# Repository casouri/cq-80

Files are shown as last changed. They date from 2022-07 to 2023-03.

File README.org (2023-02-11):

#+TITLE: CQ-80 Terminal (NAMACO端末) replica

Custom CQ-80 terminal replica! Not only is it 100% accurate, I also added Bluetooth music playback control feature. The shell is 3d printed, and the electronics are made of off-the-shelf parts.

This repository contains all the source files for the 3d model, PCB board design, etc. For a guide on making your own replica, visit: [[https://casouri.github.io/cq-80/guide-en.html][DIY Guide for CQ-80 Replica]].

For more pics, visit [[https://casouri.github.io/cq-80][CQ-80 Replica]].

#+attr_html: :width 100%
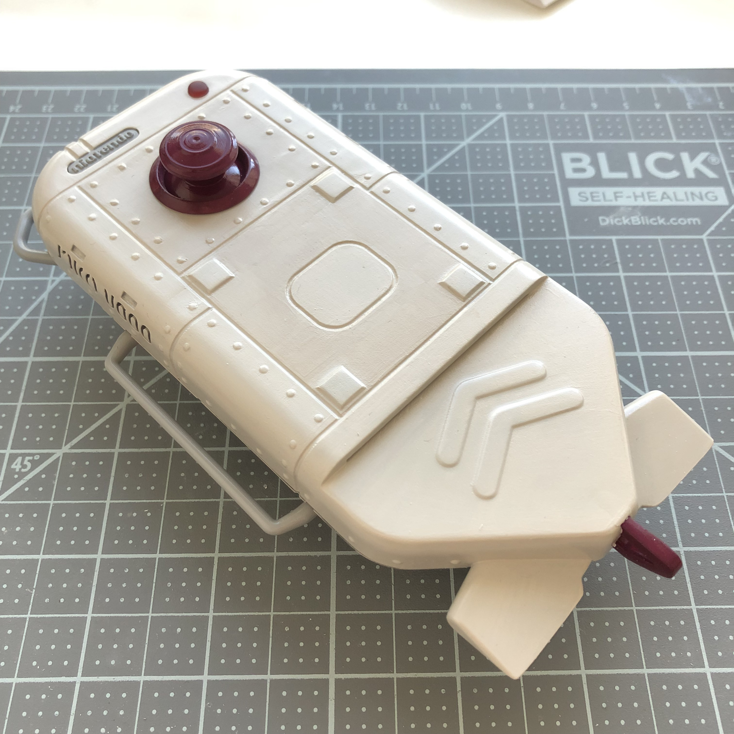
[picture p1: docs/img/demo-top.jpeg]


#+attr_html: :width 100%
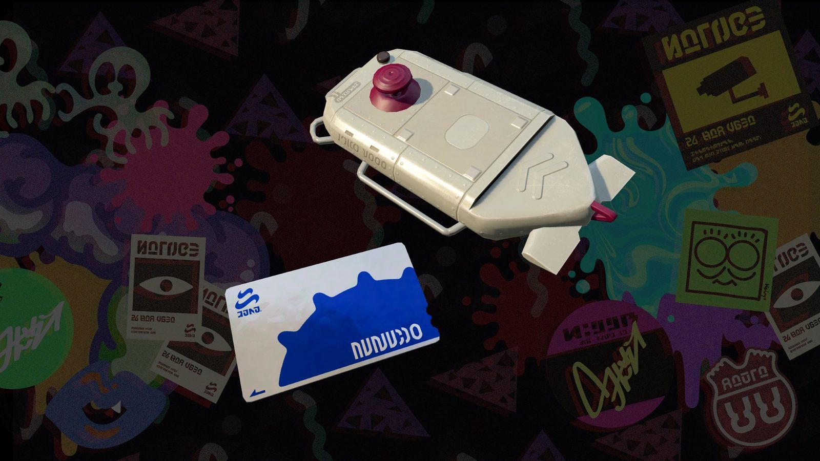
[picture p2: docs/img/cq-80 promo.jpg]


#+attr_html: :width 100%
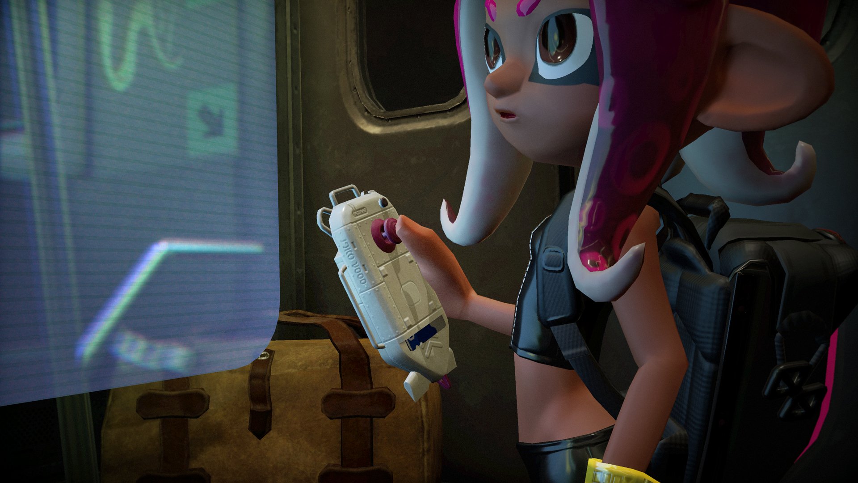
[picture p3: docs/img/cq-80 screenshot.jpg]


#+attr_html: :width 100%
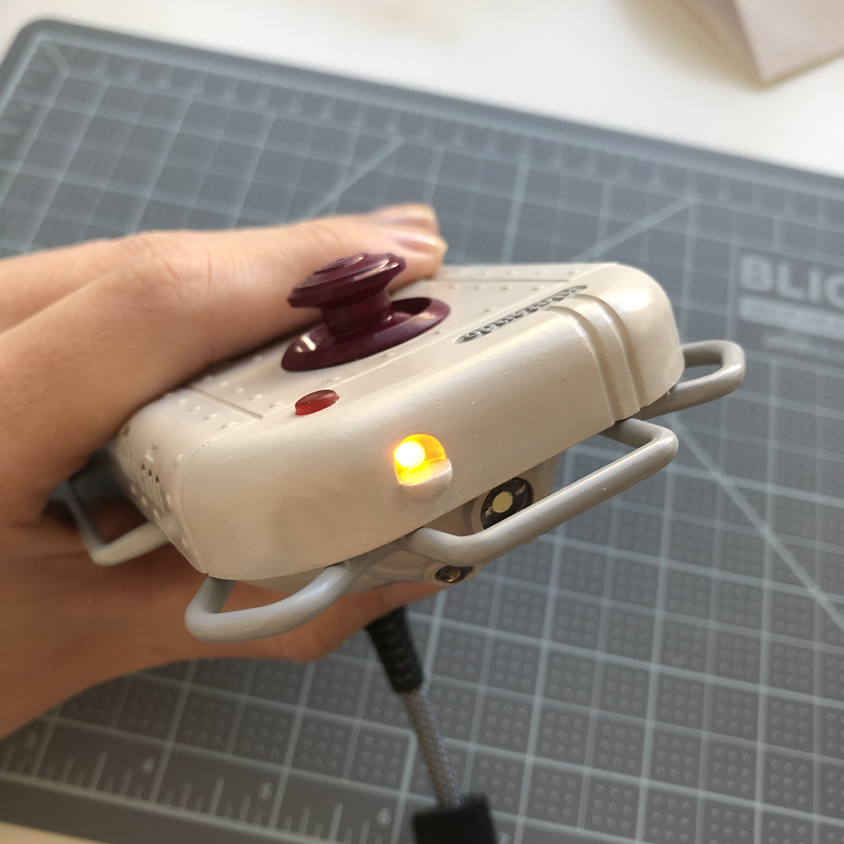
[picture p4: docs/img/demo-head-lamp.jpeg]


#+attr_html: :width 100%
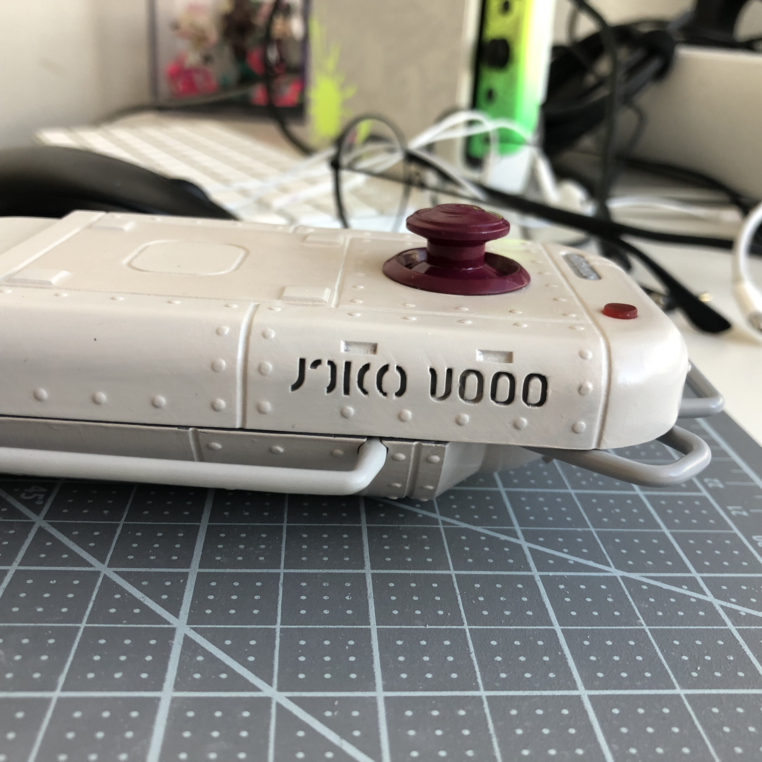
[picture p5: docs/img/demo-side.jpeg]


#+attr_html: :width 100%
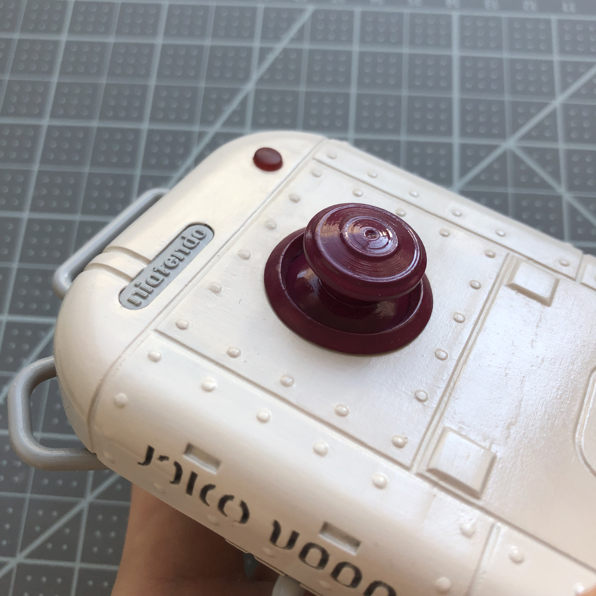
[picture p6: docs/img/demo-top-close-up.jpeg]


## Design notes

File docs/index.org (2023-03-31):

#+TITLE: CQ-80 Terminal Replica
#+HTML_HEAD: <link id="style" rel="stylesheet" type="text/css" href="./style.css"/>
#+OPTIONS: ^:nil

Custom CQ-80 terminal replica! Not only is it 100% accurate, I also added Bluetooth music playback control feature. The shell is 3d printed, and the electronics are made of off-the-shelf parts.

For a guide on making your own replica, visit: [[https://casouri.github.io/cq-80/guide-en.html][DIY Guide for CQ-80 Replica]].

#+CAPTION: Top view. The actual color is more grey than in the photo.
#+attr_html: :width 100%


#+CAPTION: The original.
#+attr_html: :width 100%


#+CAPTION: 8, my beloved...
#+attr_html: :width 100%


#+CAPTION: Font of the terminal.
#+attr_html: :width 100%
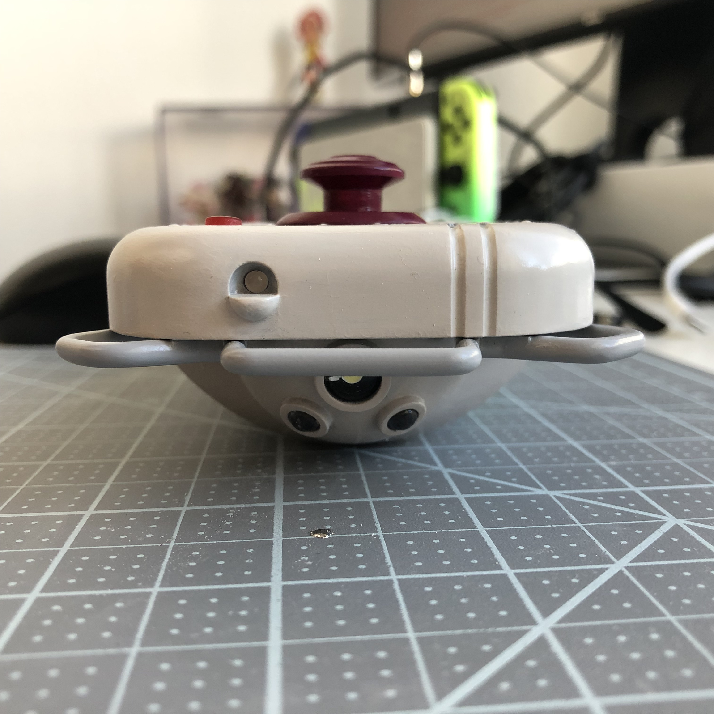
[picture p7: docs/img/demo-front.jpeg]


#+CAPTION: Compare to the in-game model.
#+attr_html: :width 100%
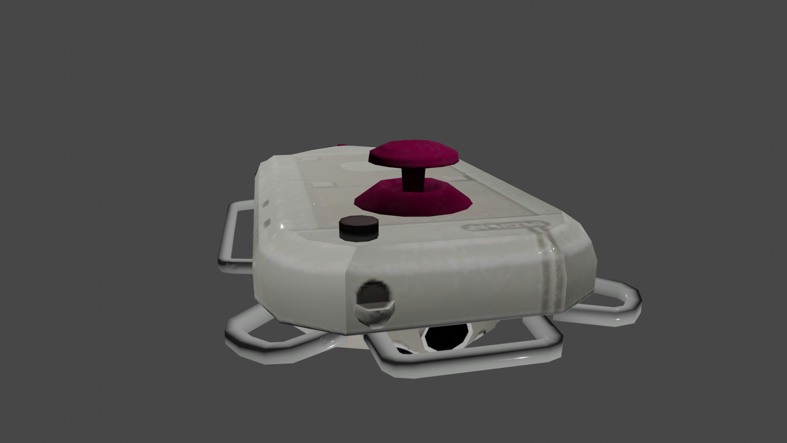
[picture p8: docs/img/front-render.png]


#+CAPTION: There are three lights in the front: one head light and two smaller side lights. The head light can be used as bathroom flashlight, and the off-white side lights can be used as night lights.
#+attr_html: :width 100%
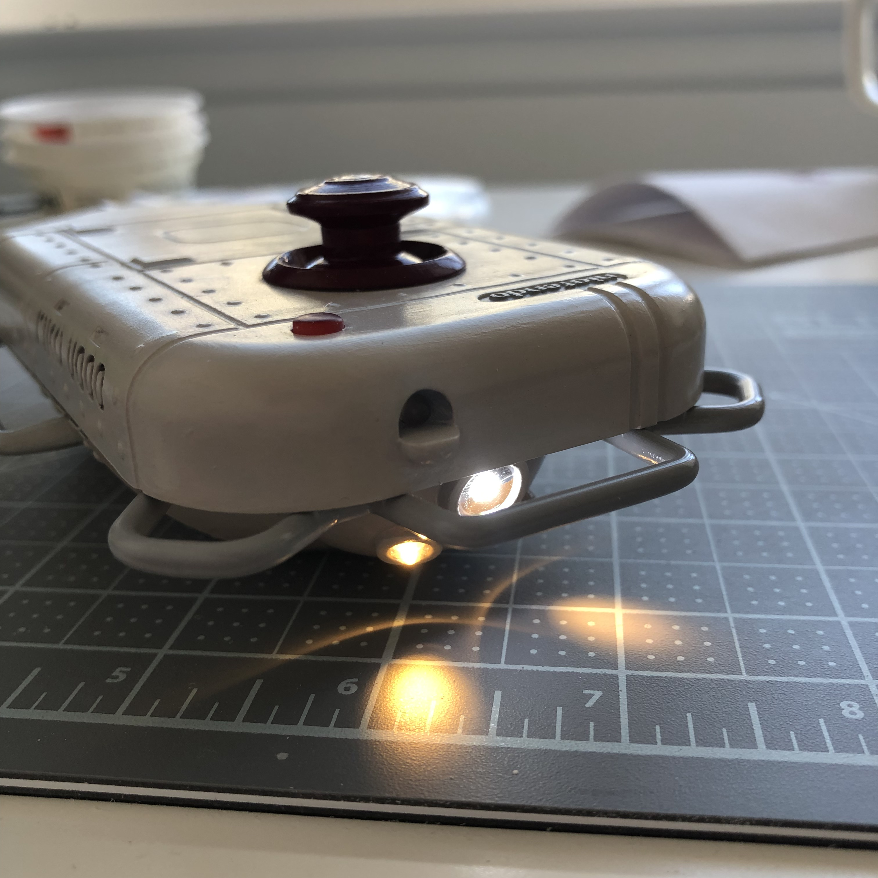
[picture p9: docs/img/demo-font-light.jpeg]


#+CAPTION: The head lamp is the charging indicator. It flashes when battery level is low, lights up when charging, and shuts off when battery is full.
#+attr_html: :width 100%


#+CAPTION: Bottom view, the USB port is the charging port.
#+attr_html: :width 100%
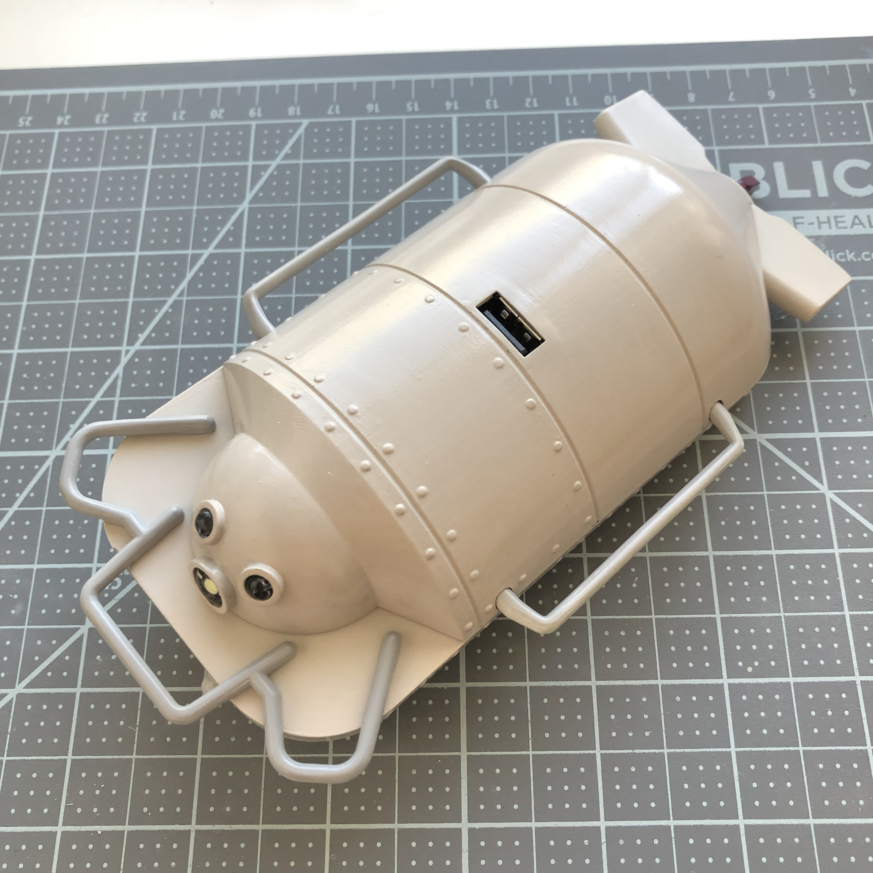
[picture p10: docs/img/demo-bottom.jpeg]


#+CAPTION: Compare to the in-game model. It has the charging port in the exact same spot.
#+attr_html: :width 100%
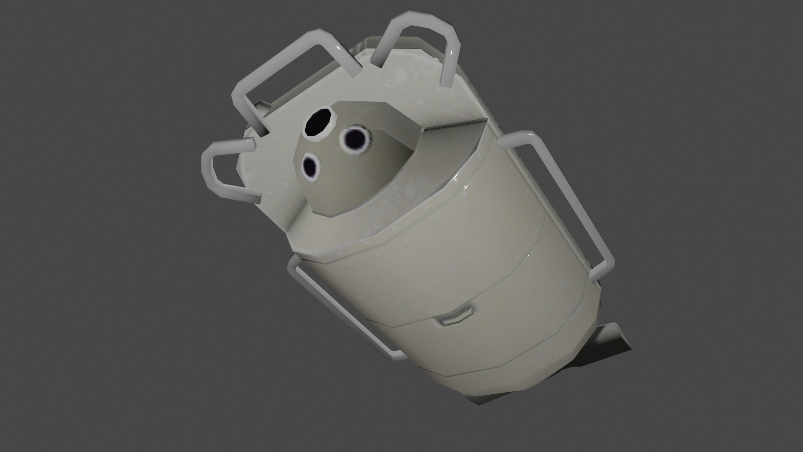
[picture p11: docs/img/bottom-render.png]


#+CAPTION: The signal light lights up when you tilt the joystick.
#+attr_html: :width 100%
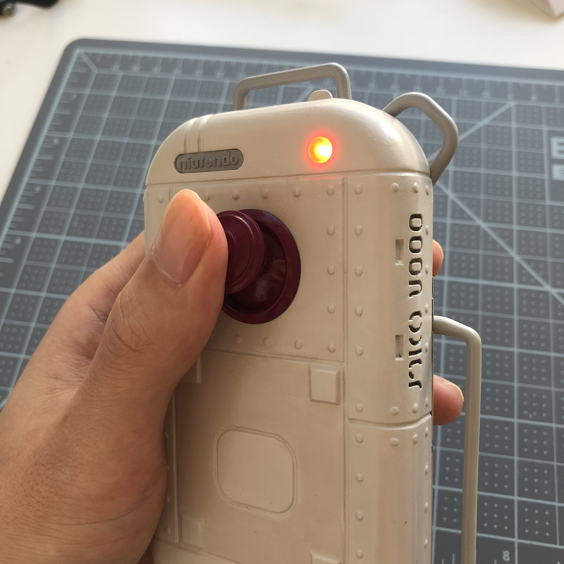
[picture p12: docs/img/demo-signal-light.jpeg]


#+CAPTION: Side emboss.
#+attr_html: :width 100%


#+CAPTION: Compare to the in-game model.
#+attr_html: :width 100%
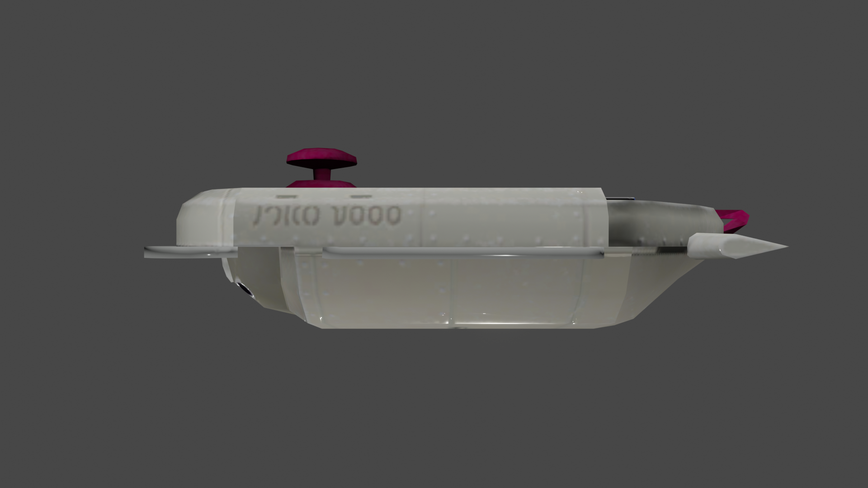
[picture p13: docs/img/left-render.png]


#+CAPTION: The tail, you can see the card slot.
#+attr_html: :width 100%
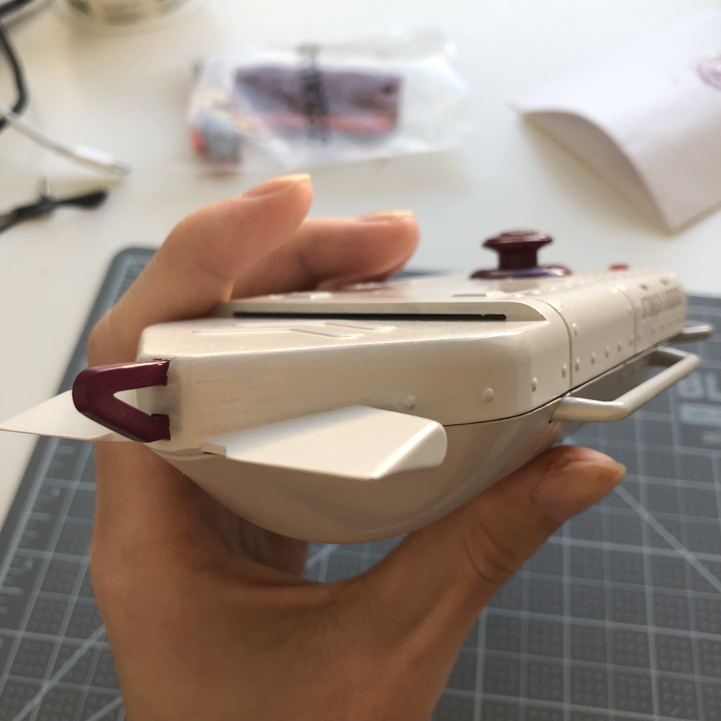
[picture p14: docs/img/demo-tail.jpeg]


#+CAPTION: A close up of the joystick.
#+attr_html: :width 100%


Here is a demo of the playback control. The controls are

| Press & hold    | Bluetooth pairing     |
| Press           | On/Off                |
| Tilt up         | Switch head lights    |
| Tilt down       | Play/Pause            |
| Tile left/right | Skip forward/backward |
| Rotate          | Volume up/down        |

#+begin_export html
<video controls width="50%">
<source src="./img/demo-playback.mp4" type="video/mp4">
</video>
#+end_export

# Local Variables:
# org-html-postamble: nil
# End:

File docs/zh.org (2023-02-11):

#+TITLE: CQ-80 Terminal (NAMACO端末)
#+HTML_HEAD: <link id="style" rel="stylesheet" type="text/css" href="./style.css"/>
#+LANGUAGE: zh-CN
#+OPTIONS: ^:nil

* 展示

自制章鱼 DLC 里的 NAMACO 终端！不光还原了外形，还加入了蓝牙音乐控制器的功能，晚上还可以把探照灯用作夜灯！3D 打印外壳和打印的电路板，不是手工达人也可以自己做！

(photo)

(photo)

(promo)

| 长按摇杆      | 匹配蓝牙设备  |
| 按一下摇杆    | 开机/关机     |
| 上推摇杆      | 切换灯光      |
| 下推摇杆      | 播放/暂停     |
| 左/右推摇杆   | 上/下一首     |
| 顺时/逆时针转 | 升高/降低音量 |

我还想加入随机/循环/快进/快退功能来着，但是可能因为这些功能不常用，电脑不能识别，可恶。

#+CAPTION: 指示灯，推动摇杆就会亮，匹配蓝牙设备的时候闪烁。

#+CAPTION: 电量指示灯，电量低的时候会缓慢闪烁，充电的时候常亮，充满电熄灭。

#+CAPTION: 头灯和副灯，副灯可以用作小夜灯，头灯可以半夜上厕所的时候当手电用www

#+CAPTION: 为了还原，终端没法容下标准尺寸的卡。读卡功能感觉有点鸡肋也没有加。

#+CAPTION: 初号机当然是紫绿配色😈

#+CAPTION: 100%细节还原。

#+CAPTION: 这个小铭牌是可以拆卸的。

#+CAPTION: 隐藏的螺丝孔。

* 还原对比

* 制作指南

这个终端还是很容易做的，毕竟部件和电路板都是打印的。只需要需要给部件染色，焊一点电子元件，上传程序到微型处理器上，最后组装到一起就行了。

因为我在北美，所以我用来 3D 打印的网站（[[https://shapeways.com][Shapeways]]）和购买各种零部件的网站对国内的乌贼来说可能没什么参考价值，想做的乌贼需要自己找一找这样的网站和商店。

** 3D 打印的部件
一共有八个需要打印的部件：顶壳底壳，摇杆和摇杆环，左右栏杆，铭牌和绳挂。3D 模型文件在 =/step= 和 =/dae= 目录下。 =step= 和 =dae= 是 3D 模型的文件格式，任何 3D 打印网站都会至少支持其中一个格式。

#+caption: 3D 打印的部件和名字标注
#+attr_html: :width 100%
#+attr_latex: :width 400px
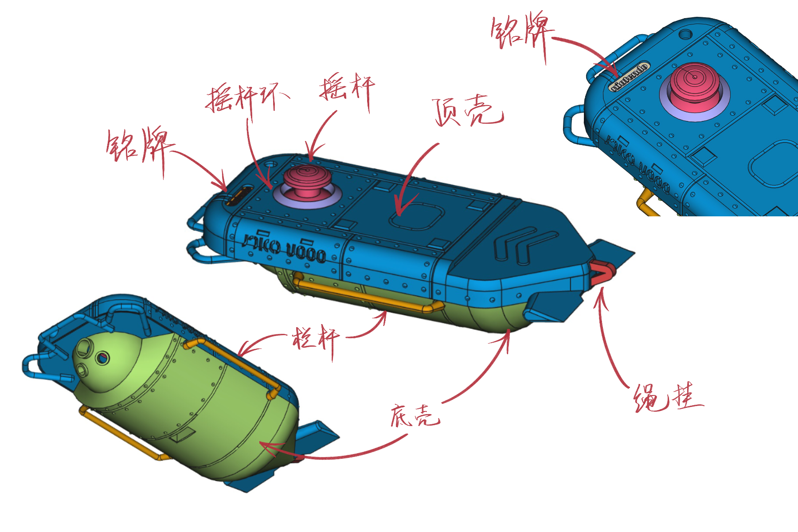
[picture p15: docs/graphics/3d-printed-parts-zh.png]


找到提供 3D 打印的网站以后，一般上传模型文件然后选择制作工艺的材料，和其他一些细节就可以了。

我推荐用 MJF 或者 SLS 的工艺和尼龙12（PA12）的材料。PA12很结实也不贵。SLA 工艺也可以，但是会更贵。

因为铭牌又小又精细，SLA 就比较适合。SLA 打印精度更高。材料的话感觉SLA支持的都可以。

别用 FDM，就是家用的 3D 打印机的工艺，精度太低，而且有些部件的结构 FDM 打印不了。

感兴趣的乌贼可以看看这篇对 3D 打印工艺的介绍：[[https://formlabs.com/blog/fdm-vs-sla-vs-sls-how-to-choose-the-right-3d-printing-technology/][3D Printing Technology Comparison: FDM vs. SLA vs. SLS]]。SLS 和 MJF 很相似，里面说的关于 SLS 的东西基本上对 MJF 也一样。

** 安装螺母
八个部件里面，顶壳底壳靠四个螺丝拧紧，摇杆环和绳挂粘在上壳上，铭牌和左右栏杆靠硬塞。电路板和USB接口也靠螺丝拧在底壳上。

我们需要在上下壳上安装螺母。这些部件设计上要求 [[M2 screws][M2 螺丝]]和 [[M2 threaded inserts][M2 热熔螺母]]。网上应该有安装热熔螺母的教程，基本上就是把螺母放在孔上，然后用电烙铁加热一下就会融化周围的塑料，使螺母嵌进去。

热熔螺母要装在这些地方：

#+caption: 螺母要装在箭头指向的位置。
#+attr_html: :width 100%
#+attr_latex: :width 400px
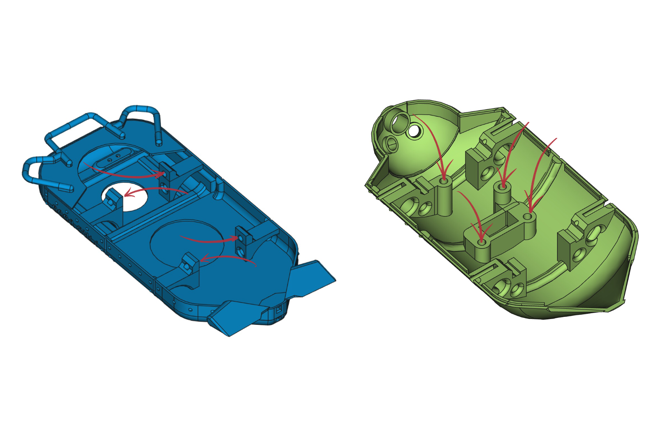
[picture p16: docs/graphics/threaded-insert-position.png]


** 给部件染色
给部件染色要用尼龙染料，因为部件是尼龙做的。我找的染料和颜色配方都是北美的，国内的乌贼自己得找一找。主体的奶灰我用的这个颜色：[[https://www.ritdye.com/color-formulas/special-white-for-nylon/?type=203&hue=0&collection=0&collaboration=0][Special White]]，紫红色的部份用的这个颜色：[[https://www.ritdye.com/color-formulas/red-candies/?type=203&hue=0&collection=0&collaboration=0][Red Candies]]。

有能力的乌贼也可以喷漆，我感觉喷漆可能更还原，因为其实终端上有不只一个颜色。喷漆的话表面估计也会更光滑。

** 把程序上传到微型处理器上
这一步需要电脑，micro USB数据线和 [[feather nrf52][Adafruit 的微型处理器]]。

1. 按照这个指南—[[https://learn.adafruit.com/bluefruit-nrf52-feather-learning-guide/arduino-bsp-setup][Arduino Support Setup]]—安装 Arduino IDE。我们用的处理器是 nRF53832。
1. 按照这个指南—[[https://learn.adafruit.com/bluefruit-nrf52-feather-learning-guide/arduino-board-setup][Arduino Board Testing]]—测试一下板子能用，我们能上传程序。
1. 用 Arduino IDE 打开 =/arduino/controller/controller.ino=，把程序上传到处理器。

** 打印电路板
我们要打印两个电路板，一个主板（=/board=），一个 USB 接口（=/usb_breakout=）。国内打印电路板的网站应该挺多的，随便找一个，把 zip 文件上传到网站上（=/board/board.zip= 和 =/usb_breakout/usb_breakout.zip=）就行了。

** 焊接电子部件
1. 把微型处理器焊到[[main board][主板]]上
1. 把[[joystick][摇杆]]焊到主板上
1. 把[[usb type-A connector][USB 接口]]焊到[[usb breakout][USB接口板]]上
1. 把[[usb breakout][USB 接口板]]连到[[micro usb breakout][micro-USB 接口板]]上
1. 把[[resistors][电阻]]焊到主板上
1. 把[[header pins][金属接头]]焊到主板 [[LED’s][LED]] 的位置上
1. 给 LED连上[[jumper wires][电线]]

当然，LED想要什么颜色都可以，只要尺寸对就行。

TODO (solder instruction graphics)

** 组装

底壳：
1. 用螺丝把usb接口拧在底壳上
1. 用螺丝把主板拧在底壳上
1. 把micro usb接头插到微型处理器上
1. 把摇杆装上

顶壳：
1. 把摇杆环粘上
1. 把四个 LED 装上
1. 把绳挂粘上
1. 把电池粘上

组装：
1. 把 LED 的线插到主板对应的接头上
1. 把电池插到微型处理器上
1. 上下壳装好
1. 把左右栏杆插上

* 部件明细
3D 打印的部件（在 =/step= 和 =/dae= 里有模型文件）：
- 顶壳（top） <<top shell>>
- 底壳（bottom） <<bottom shell>>
- 摇杆（thumbstick） <<thumbstick>>
- 摇杆环（thumbstick guard） <<thumbstick guard>>
- 左右栏杆（side bars） <<side bars>>
- 铭牌（trademark） <<trademark insert>>
- 绳挂（hanger） <<hanger>>

机械零件：
- M2 [[https://www.amazon.com/s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][螺丝]] (8mm 长) × 4 <<M2 screws>>
- M2 螺丝 (4mm) × 4
- 热熔 M2 [[https://www.amazon.com/s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][螺母]] (4mm × 3.5mm) (长度 × 外径) × 8 <<M2 threaded inserts>>

打印的电路板：
- 主板 (=/board/upload.zip=) <<main board>>
- USB 接口板 (=/usb_breakout/upload.zip=) <<usb breakout>>

电子零件：
- [[https://www.adafruit.com/product/3406][Adafruit Feather nRF52 Bluefruit LE (nRF52832)]] (nRF52840 should also work if you know how to modify the program) <<feather nrf52>>
- [[https://www.adafruit.com/product/2011][Adafruit Lithium Ion Battery 3.7V 2000mAh]] <<lipo battery>>
- [[https://www.amazon.com/s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][Alps RKJXV1224 joystick]] (aka switch pro controller replacement joystick) <<joystick>>
- [[https://www.digikey.com/en/products/detail/molex/1050570001/3045207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][Molex USB 2.0 type-A female vertical mount connector]] (product number ‎1050570001‎) <<usb type-A connector>>
- [[https://www.digikey.com/en/products/detail/sparkfun-electronics/BOB-10031/5673778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][Sparkfun USB micro-B male breakout]] (product number BOB-10031) <<micro usb breakout>>
- Micro USB 线（用来上传程序）
- [[https://www.amazon.com/s?k=USB+male+to+USB+male&ref=nb_sb_noss][USB 公对公线]]（用来给终端充电）

电子耗材：
- [[https://www.amazon.com/s?k=5mm+led&crid=1DRG7DU8VXT7J&sprefix=5mm+led%2Caps%2C145&ref=nb_sb_noss_1][5mm red LED]] × 1 （指示灯） <<LED’s>>
- [[https://www.amazon.com/s?k=3mm+led&crid=4JJ4EKJP17Q3&sprefix=3mm+le%2Caps%2C131&ref=nb_sb_noss_2][3mm green LED]]  × 1 （电量指示灯）
- [[https://www.amazon.com/s?k=8mm+led&crid=FJQQ6UVY7NAI&sprefix=8mm+led%2Caps%2C140&ref=nb_sb_noss_1][8mm white LED]] × 1 （头灯）
- [[https://www.amazon.com/s?k=5mm+led&crid=1DRG7DU8VXT7J&sprefix=5mm+led%2Caps%2C145&ref=nb_sb_noss_1][5mm warm-white LED]] × 2 （副灯）
- [[https://www.amazon.com/s?k=resistors&crid=1G02OHEC2Z4WT&sprefix=resistors%2Caps%2C129&ref=nb_sb_noss_1][电阻]]，220Ω × 4，100KΩ × 1。具体电阻不需要很精确，220Ω的50到300都可，100K的10K–100K都行。<<resistors>>
- [[https://www.amazon.com/s?k=jumper+wires&crid=JYYBJ45HZ3F3&sprefix=jumper+wire%2Caps%2C144&ref=nb_sb_noss_1][跳线（母）]]<<jumper wires>>
- [[https://www.amazon.com/s?k=header+pins&ref=nb_sb_noss][金属接口]]<<header pins>>
- [[https://www.amazon.com/s?k=lcd+tape&crid=2K79ZJAOILAMF&sprefix=lcd+tape%2Caps%2C127&ref=nb_sb_noss_1][LCD 胶带]]（手机里粘屏幕电池的那种） <<LCD tape>>

染料：
- [[https://www.ritdye.com/products/sandstone/][Rit DyeMore Sand Stone]] <<dye>>
- [[https://www.ritdye.com/products/super-pink/][Rit DyeMore Super Pink]]
- [[https://www.ritdye.com/products/racing-red/][Rit DyeMore Racing Red]]

工具：
- 电烙铁套装（[[https://www.amazon.com/s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][电烙铁和焊锡]]，[[https://www.amazon.com/s?k=third+hand&crid=Y0U8J28EO3EJ&sprefix=third+hand%2Caps%2C139&ref=nb_sb_noss_1][架子]]）<<soldering iron>>
- [[https://www.amazon.com/dp/B08B17VQLD?psc=1&ref=ppx_yo2ov_dt_b_product_details][装热熔螺母的电烙铁头]] <<heat-set insert tip>>

# Local Variables:
# org-html-postamble: nil
# End:

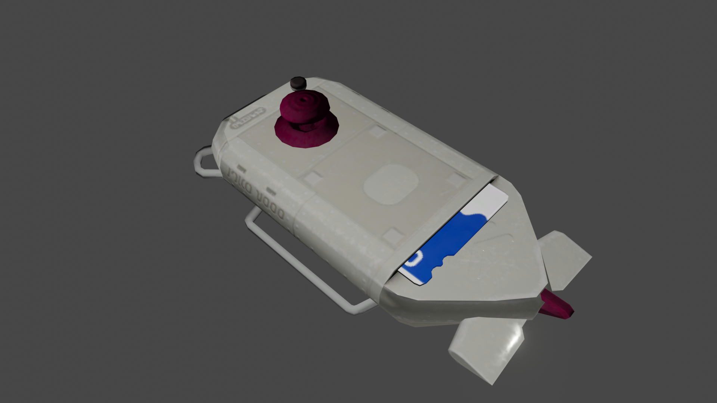
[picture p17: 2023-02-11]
docs/img/top-render.png

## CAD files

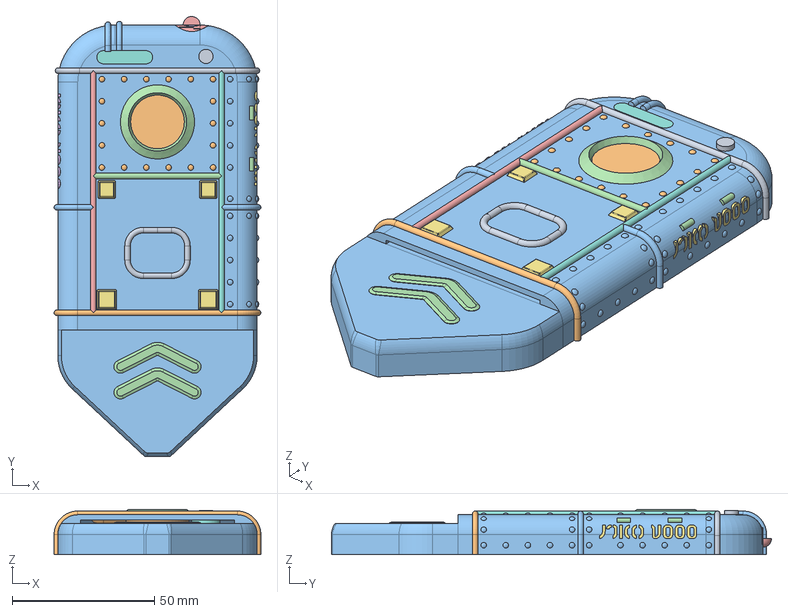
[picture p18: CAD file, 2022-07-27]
cq-80.FCStd
72.6 x 154.4 x 15.9 mm
top groove
bottom groove
middle side groove
middle groove
left groove
bump master
square bumps
right groove
belly button
bump top
bump side (Mirror #1)
cylinders (Mirror #2)
front light bottom
front light top cutout
front light hole
top light shell
top light cutout
joystick hole
joystick guard
front light top shell
left emboss cutout
right emboss cutout
trademark cutout
trademark
trademark support
trademark groove
arrows
emboss support
front light support

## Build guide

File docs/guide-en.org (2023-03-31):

#+TITLE: CQ-80 Terminal Replica DIY Guide
#+HTML_HEAD: <link id="style" rel="stylesheet" type="text/css" href="./style.css"/>
#+OPTIONS: ^:nil

* Overview
The CQ-80 replica is made of 3d-printed parts and (mostly) off-the-shelf electronic parts. The electronics allow it to connect to a computer via Bluetooth and control music playback. (It’s possible to exclude electronics, see below.)

To make the replica, you need to 3d-print the parts, paint them, buy all the electronics, solder them, upload a program to the microcontroller, and finally assemble everything together. I’d say that fitting the parts and painting them are the most difficult and time-consuming steps in the whole process.

Disclaimer: I’m an utter armature on 3d modeling, electronics and model painting. So dispite my best effort, there are short-comings all over the place. If you have any suggestion/feedback, I appreciate them very much.

NOTE!! The v3.0 (the latest) 3D models doesn’t match some of the photos below (taken from a v2.1 model), because I’ve made updates to the model but haven’t printed them yet (because reasons). But those changes are mostly minor, so it shouldn’t be a problem.

* Download files

Download model and PCB files from here: TODO (it just links to the GitHub release). Unpack it and you should see two directory, =stl= ad =controller=, and two zip files, =board.zip=, =usb_breakout.zip=. The =stl= directory contains 3d model files; the =controller= directory is the Arduino program, and =board.zip= and =usb_breakout.zip= are files for printing the PCB board. Their use are explained as we go through each step.

* 3d-printed parts
There are eight parts: the top and bottom shells, thumbstick and thumbstick guard, front bar, left and right side bars, the trademark insert on the top, and the hanger at the tail. The 3d model files for them are in the =stl= folder. I combined smaller parts together into a single file, so you only need to print three main parts: the top shell, the bottom shell, and the small parts combined.

I made the trade mark insert a separate piece, so you can design a custom insert and use that instead.

#+caption: 3d-printed parts and their canonical name
#+attr_html: :width 100%
#+attr_latex: :width 400px
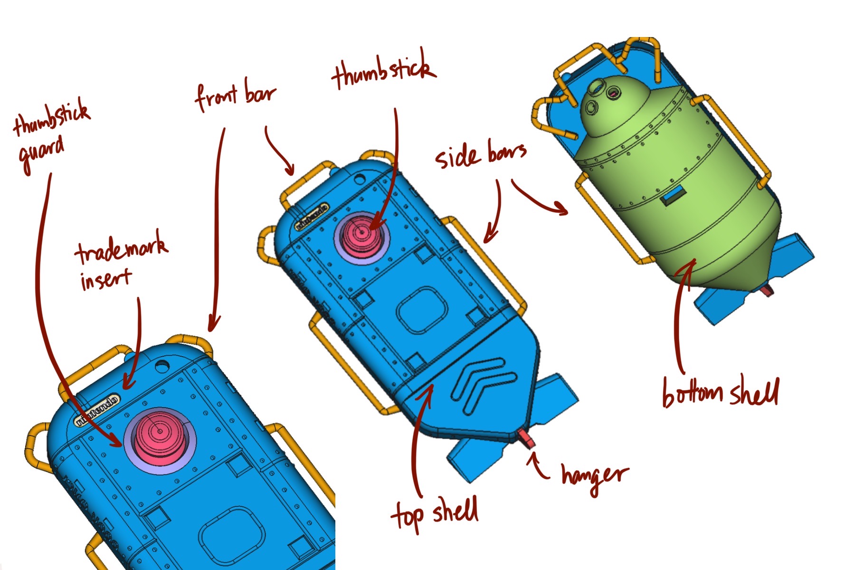
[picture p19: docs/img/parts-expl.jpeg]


I recommend printing using resin. MJF or SLS are ok, but they have fuzzy detail and uneven surface, and we don’t need the strength they provide. A strong resin is more than enough for our parts. Don’t use FDM. Its resolution is too low, and some structures in the parts simply cannot be printed with FDM.

I used pcbway.com for printing, they so much cheaper than sites like Shapeways and Xometry, and the result is not bad. If you are not concerned with budget, you can try Xometry, their quality is top-notch (but I haven’t tried their resin prints, only SLS prints). On pcbway.com I printed the top and bottom shell with Resin Somos EvoLVe 128, and the small parts with Resin UTR 8220. All three parts combined costs around $50 including shipping, really can’t complain.

[Here is a description of 3d-printing technologies I mentioned above: [[https://formlabs.com/blog/fdm-vs-sla-vs-sls-how-to-choose-the-right-3d-printing-technology/][3D Printing Technology Comparison: FDM vs. SLA vs. SLS]]. SLS and MJF are quite similar, what it says about SLS pretty much applies to MJF too.]

* Fitting the parts

Once you receive the parts, you need to sand/file them a bit here and their so everything fits together. The fitting in the digital model is pretty tight, since you can always sand down tight fits but it’s really hard to fix a loose fit.

You can get some small files (round, square and flat) from local hobby stores, they are very handy for fitting parts.

* Install threaded inserts to the printed parts
Out of the eight parts, top and bottom shell are fastened together by two screws, thumbstick guard and hanger are glued to the top shell, and trademark insert and side bars are friction-fit. The PCB board and USB breakout board are screwed into the bottom shell.

Therefore, we need to install threaded inserts to top and bottom shells. The parts are designed to use [[M2 screws][M2 screws]] and [[M2 threaded inserts][M2 threaded inserts]]. Here is a tutorial on installing heat-set inserts: /[[https://markforged.com/resources/blog/heat-set-inserts][Using Heat Set Inserts]]/. You need [[soldering iron][iron]] and [[heat-set insert tip][heat-set insert tip]] (or just the iron tip, it works ok). /Do not press too hard/ when installing threaded inserts: the resin is strong but brittle, and is heat-resistant, so pressing too hard will break it. Be patient and press it in little by little.

Install inserts on these places:

#+caption: Top shell
#+attr_html: :width 100%
#+attr_latex: :width 400px
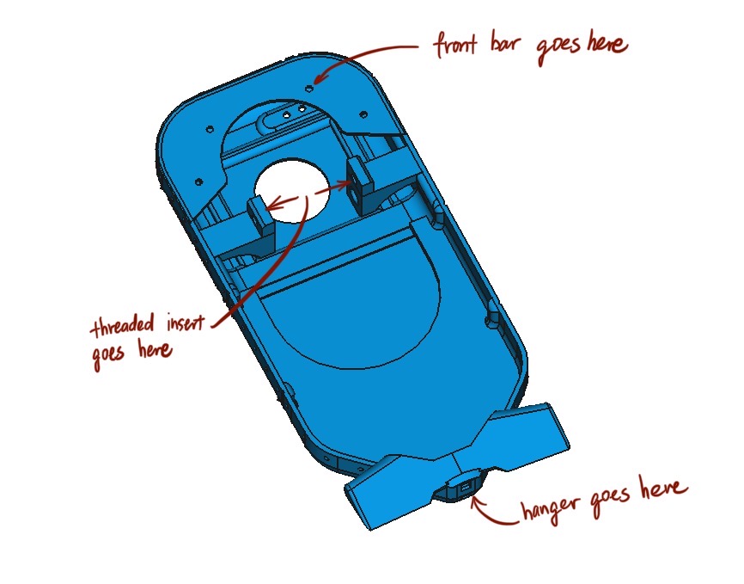
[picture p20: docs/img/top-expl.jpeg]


#+caption: Bottom shell
#+attr_html: :width 100%
#+attr_latex: :width 400px
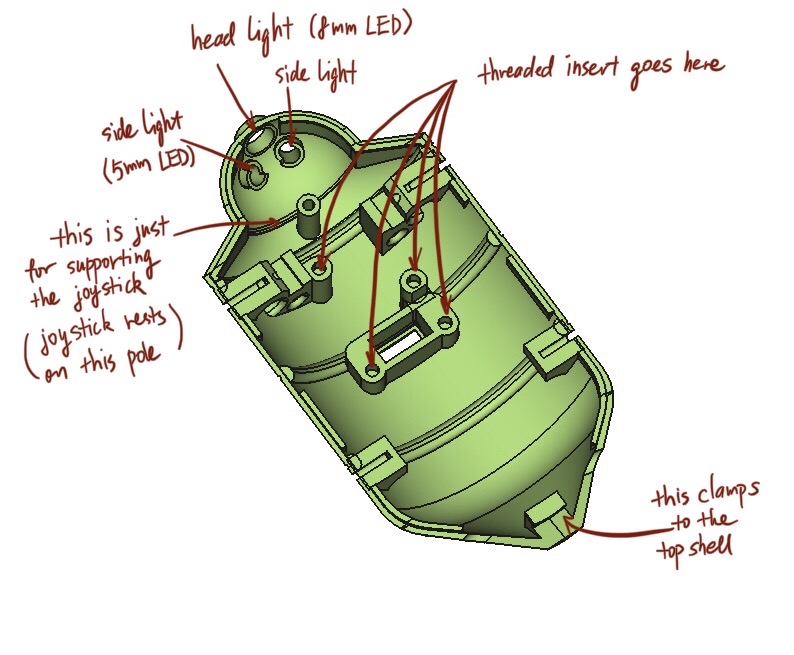
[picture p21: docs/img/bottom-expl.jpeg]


* Uploading the program to the microcontroller
You need a computer, a micro-usb cable and the [[feather nrf52][Adafruit microcontroller]].

1. Follow this guide—[[https://learn.adafruit.com/bluefruit-nrf52-feather-learning-guide/arduino-bsp-setup][Arduino Support Setup]]—to install Arduino IDE and support software. The board we use is nRF52832, follow instructions for nRF52832 and ignore ones for nRF52840.
1. Test that everything is working fine by following this guide—[[https://learn.adafruit.com/bluefruit-nrf52-feather-learning-guide/arduino-board-setup][Arduino Board Testing]]. Don’t skip this step.
1. Use the Arduino IDE to open =/arduino/controller/controller.ino=, and hit the right-pointing arrow to upload the program. The board and port settings should be already set by the previous step when we test the board.

* Printing PCB boards
There are two boards to print, the main board (=board.zip=) and the USB breakout board (=usb_breakout.zip=). I used [[https://oshpark.com/][OSHPARK]] to print PCB boards. There are cheaper providers that I haven’t tried like [[https://www.pcbway.com/][pcbway]] and [[https://jlcpcb.com/][jlcpcb]].

Take OSHPARK as an example, go onto their website and click “browse for files”, and choose the zip file for the board, upload it, then hit continue all the way. Use USPS for shipping ;-)

* Soldering electronic parts
/Test before soldering any parts!/ Test that the LED’s and resistors work! You’ll be in a world of pain if you find out a resister is bad /after/ you’ve soldered it to the board.

1. Solder the microcontroller to the [[main board][main board]]
1. Solder the [[joystick][joystick]] to the main board (you need to clip the two nubs under the joystick part because I forgot to create holes on the pcb board design)
1. Solder the [[usb type-A connector][USB female connector]] to the [[usb breakout][USB breakout board]]
1. Connect the [[usb breakout][USB breakout board]] to the [[misco-USB connector][micro-USB connector]] (the square hole on the breakout is ground)
1. Solder [[resistors][resistors]] to the main board (for the LED’s anything around 100ω is fine, for the battery detection, use something large like 10kω)
1. Solder [[header pins][header pins]] for the [[LED’s][LED’s]] to the main board
1. Solder some [[jumper wires][jumper wires]] to the LED’s and connect them to the header pins on the main board.

Of course, you can use LED’s of whatever color you like, just make sure the dimensions (5mm, 3mm, 8mm) are right.

#+caption: Main board
#+attr_html: :width 100%
#+attr_latex: :width 400px
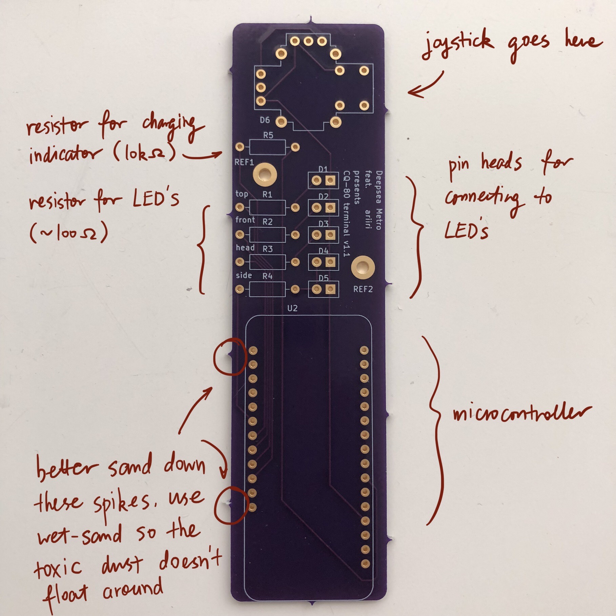
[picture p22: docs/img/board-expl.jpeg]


#+caption: USB board.
#+attr_html: :width 100%
#+attr_latex: :width 400px
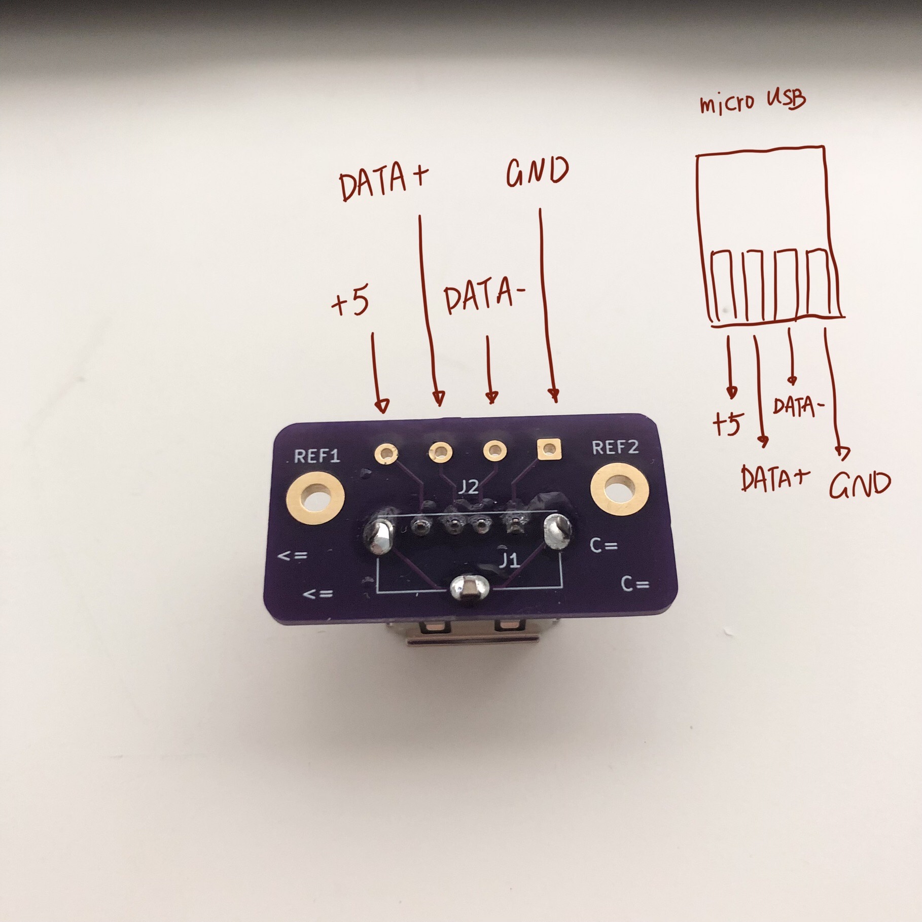
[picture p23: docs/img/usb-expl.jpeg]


* Painting the parts
** Materials

I don’t have aerospray so I hand-painted the parts. I tried to use paints that are allegedly friendly to hand-painting. You can find a list of the paints I used below in the [[painting][painting]] section.

If you don’t want to hand-paint and don’t have aerospray, you can get some spray cans and spray paint. I didn’t spray paint because I couldn’t find the exact color I want. When buying spray paint, make sure to by spray paints for modeling, like Tamiya and Mr. Hobby, not ones for graffiti or painting furnitures.

I used [[Pallid Wych Flesh][Pallid Wych Flesh]] (off-white) for the primary color of the top shell, and [[Pallid Wych Flesh][Pallid Wych Flesh]] mixing in a little bit [[Rakarth Flesh][Rakarth Flesh]] (brownish) for the bottom shell and the alt color on the top shell. For the violet red color (thumbstick, etc), I mixed [[Violet Red][Violet Red]] plus a little bit of [[Carmine Red][Carmine Red]]. Carmine Red is probably optional, if you don’t mind your thumbstick to be a bit more purple than the official one.

This is the rough ratio for the paints, to the best of my recollection:

- Top shell :: Pallid Wych Flesh
- Bottom shell & top shell alt :: Pallid Wych Flesh : Rakarth Flesh = 7 : 1, maybe
- Thumbstick, etc :: Violet Red : Carmine Red = 5 : 1, possibly
- Grey parts :: Just the color of light grey primer (see below)

I really don’t remember... Luckily the two colors that requires mixing have large rooms of error.

** Steps for painting
I learned this from watching accumulatively ~4.78 hrs of gunpla and 3d printing videos on YouTube, so don’t take my word for everything.

But anyway, you need to first fill the gaps like print-lines or other imperfections with [[acrylic putty][acrylic putty]], then sand the surfaces smooth. It should be very smooth to the touch, because any small imperfections you can’t see right now will show when you put on paint. You can get some [[./photos/sanding-sponge.jpeg][sanding sponge]] which are very handy when sanding small models like this (you can find them at a local hobby store). I suggest you leave the putty to dry for at least a couple hours, ideally overnight, before sanding. Just casually put on some putty, let it dry, sand it next day, add more putty if necessary, and repeat. Take it slow and easy. Don’t rush it or get it done in one afternoon. This advice applies to the following steps as well.

Once the surface is smooth, prime your parts with a [[light grey primer][light grey primer]]. For grey parts this is all they need. For other parts, the next step is to apply paint.

I suggest you first watch some hand-painting gunpla/miniature tutorials on YouTube before doing it, because it’s not too easy. Buy some nice, soft acrylic painting brush, don’t use cheap ones. The key seems to be thinning the paint just right: not too thin and not too thick. Also be patient and work layer by layer. The first and second layers are going to look really bad and it’s fine, after several layers you should get a pretty uniform color. If you are patient and apply thin layers, there is a larger room of error.

Finally, let the paint dry for a couple of hours and spray all the parts with a layer or two of clear top-coat to protect the paint. I used [[gloss top-coat][gloss top-coat]] because the in-game render seems to be glossy. And the end result is indeed very nice. If you want, you can use flat or half-gloss top-coat. After applying the top-coat, I suggest you to leave it along for at least a couple hours, ideally a day before touching it.

* Assembly
Bottom shell:
1. Install the LED’s. I suggest using hot glue gun to glue them in-place. Also make sure you test the LED’s before gluing them.
1. Screw the USB breakout to the bottom shell
1. Plug in the battery to the microcontroller
1. Plug in the micro USB plug to the micro controller
1. Screw the main board to the bottom shell, tuck the battery under the main board

Top shell:
1. Glue the thumstick guard into place, I used super glue
1. Glue the LED’s into place, I used hot glue gun
1. Glue the hanger into place (super glue)
1. Glue the front bars (super glue)

Assemble:
1. Plug in LED’s wires to the main board
1. Install the thumbstick
1. Screw the top and bottom shell together
1. Install side bars.

#+caption: Installing the USB breakout board. Technically you only need to connect the +5 and GND pins, like I did here. These two pins allows you to charge the battery through the USB port. But if you connect all four pins, you can use the USB port for uploading programs as well.
#+attr_html: :width 100%
#+attr_latex: :width 400px
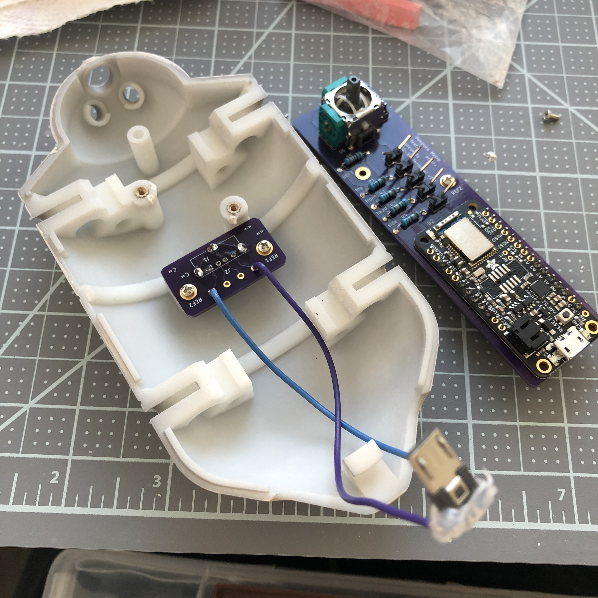
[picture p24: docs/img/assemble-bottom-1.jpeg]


#+caption: Installing the main board.
#+attr_html: :width 100%
#+attr_latex: :width 400px
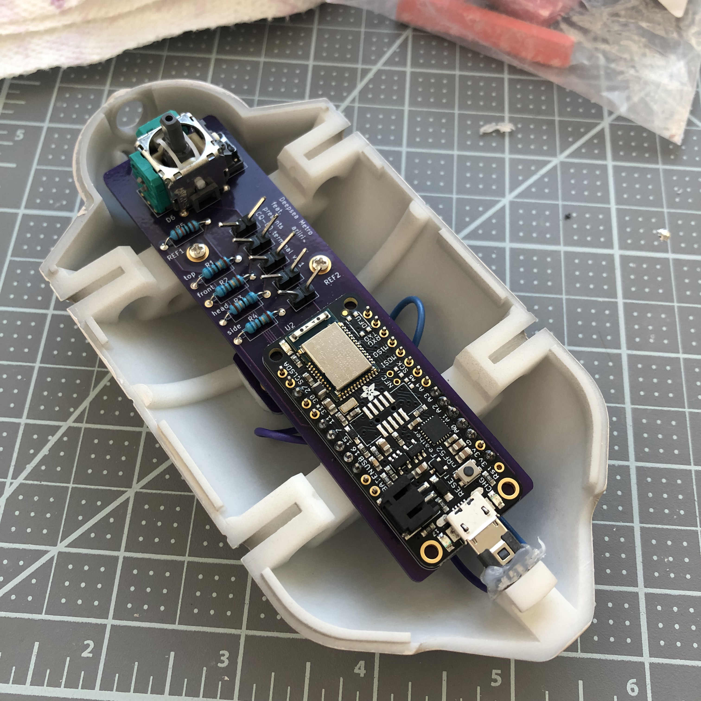
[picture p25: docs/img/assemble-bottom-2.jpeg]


* Caring
Even though we sprayed a protective top-coat, the paint is still easily damaged: I’ve had small dents on the CQ-80 that are deep enough to reveal underling primer. I guess spray painitng will give you a thinner and more robust paint, I’m also contemplating on using auto top-coats, I’ll report back with the result.

Anyway, the best way to protect the paint job is to not knock anything into it. Put it in a bag or a crystal coffin so nothing sharp can hit it.

* If you don’t want the electronics
It should be quite feasible to do away all the electronics, should you only want the plastic model and don’t care about the music controller functionality. It’ll also cut the cost by a lot. You still need the [[joystick][joystick]], just glue it to a cardboard or something, and glue the cardboard to the pole right under the joystick. I’d also reinforce the pole, eg, smudge a pile of hot glue around it.

* Parts listing

3d-printed parts (in the =stl= folder):
- <<top shell>> Top shell
- <<bottom shell>> Bottom shell
- <<thumbstick>> Thumbstick
- <<thumbstick guard>> Thumbstick guard
- <<front bar>> Front bar
- <<side bars>> Side bars
- <<trademark insert>> Trademark insert
- <<hanger>> Hanger

Mechanical parts:
- <<M2 screws>> M2[fn:m2] [[https://www.amazon.com/s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][screws]] (8mm in length) × 4
- M2 screws (4mm) × 4
- <<M2 threaded inserts>> Heat-set[fn:heat-set] M2 [[https://www.amazon.com/s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][threaded inserts]] (4mm × 3.5mm) (length × outer diameter) × 8

Printed PCB boards:
- <<main board>> Main board (=board.zip=)
- <<usb breakout>> USB breakout (=usb_breakout.zip=)

Electronic parts:
- <<feather nrf52>> [[https://www.adafruit.com/product/3406][Adafruit Feather nRF52 Bluefruit LE (nRF52832)]] (nRF52840 should also work if you know how to modify the program)
- <<lipo battery>> [[https://www.adafruit.com/product/258][Adafruit Lithium Ion Battery 3.7V 1200mAh]]
- <<joystick>> [[https://www.amazon.com/s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][Alps RKJXV1224 joystick]] (aka switch pro controller replacement joystick)
- <<usb type-A connector>> [[https://www.digikey.com/en/products/detail/molex/1050570001/3045207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][Molex USB 2.0 type-A female vertical mount connector]] (product number ‎1050570001‎)
- <<misco-USB connector>> [[https://www.amazon.com/gp/product/B07G5ZY7MH/ref=ppx_yo_dt_b_search_asin_title?ie=UTF8&psc=1][USB Micro-B connector]] (anything similar-sized should work)
- Micro USB to USB cable (for uploading the program to the microcontroller)
- [[https://www.amazon.com/s?k=USB+male+to+USB+male&ref=nb_sb_noss][USB male to USB male cable]] (for charging CQ-80)

Electronic consumables:
- <<LED’s>> [[https://www.amazon.com/s?k=5mm+led&crid=1DRG7DU8VXT7J&sprefix=5mm+led%2Caps%2C145&ref=nb_sb_noss_1][5mm red LED]] × 1 (top light)
- [[https://www.amazon.com/s?k=3mm+led&crid=4JJ4EKJP17Q3&sprefix=3mm+le%2Caps%2C131&ref=nb_sb_noss_2][3mm green LED]]  × 1 (front lamp)
- [[https://www.amazon.com/s?k=8mm+led&crid=FJQQ6UVY7NAI&sprefix=8mm+led%2Caps%2C140&ref=nb_sb_noss_1][8mm white LED]] × 1 (head light)
- [[https://www.amazon.com/s?k=5mm+led&crid=1DRG7DU8VXT7J&sprefix=5mm+led%2Caps%2C145&ref=nb_sb_noss_1][5mm warm-white LED]] × 2 (side lights)
- <<resistors>> [[https://www.amazon.com/s?k=resistors&crid=1G02OHEC2Z4WT&sprefix=resistors%2Caps%2C129&ref=nb_sb_noss_1][Resistors]], 110Ω × 4, 10KΩ × 1. The resistance doesn’t have to be exact, 110Ω ones can be replaced by any resistor in the range of 50 to 300 ohms, and the 10K one can be replaced by any in the 10K-100K range.
- <<jumper wires>> [[https://www.amazon.com/s?k=jumper+wires&crid=JYYBJ45HZ3F3&sprefix=jumper+wire%2Caps%2C144&ref=nb_sb_noss_1][Jumper wires (female)]] (alternatively you can buy normal wires and [[https://www.amazon.com/s?k=dupont+pins&crid=2OT1FVWMB4KVE&sprefix=dupon+pins%2Caps%2C181&ref=nb_sb_noss][Dupont pins]] and make jump wires yourself)
- <<header pins>> [[https://www.amazon.com/s?k=header+pins&ref=nb_sb_noss][Header pins]]

<<painting>>
Painting:
- <<Pallid Wych Flesh>> [[https://www.games-workshop.com/en-US/Layer-Pallid-Wych-Flesh-2019][Citadel Colour, Layer, Pallid Wych Flesh]]
- <<Rakarth Flesh>> [[https://www.games-workshop.com/en-US/Base-Rakarth-Flesh-2019][Citadel Colour, Base, Rakarth Flesh]]
- <<Violet Red>> [[https://acrylicosvallejo.com/en/product/hobby/model-color-en/violet-red-70812/][Vallejo Model Color 70.812 Violet Red]]
- <<Carmine Red>> (optional) [[https://acrylicosvallejo.com/en/product/hobby/model-color-en/carmine-red-70908/][Vallejo Model Color 70.908 Carmine Red]]
- <<acrylic putty>> [[https://acrylicosvallejo.com/en/product/crafts/auxiliaries-decorative-arts/plastic-putty/][Vallejo 70.401 Plastic Putty]]
- <<light grey primer>> [[https://www.tamiyausa.com/shop/finishing/fine-surface-primer-l/][Tamiya Fine Surface Primer Light Grey Spray Can]]
- <<gloss top-coat>> [[https://www.mr-hobby.com/en/product2/category_11/272.html][Mr. Super Clear UV Cut Gloss Top Coat]] (Tamiya or Mr. Hobby doesn’t matter, any top-coat should work)
- Sanding sponge I mentioned earlier, should be easily found in local hobby stores

Tools:
- <<soldering iron>> Soldering kit ([[https://www.amazon.com/s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][iron & tin]], [[https://www.amazon.com/s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][third hand]]) (for soldering and installing threaded inserts)
- <<heat-set insert tip>> (optional) [[https://www.amazon.com/dp/B08B17VQLD?psc=1&ref=ppx_yo2ov_dt_b_product_details][Heat-set insert tip]] (for installing threaded inserts)
- Acrylic brushes

[fn:m2] “M2” is the “size” of the screw, read /[[https://www.hubs.com/knowledge-base/thread-types/][Thread types: The practical engineer’s guide]]/ for some explanations.

[fn:heat-set] “Heat-set” means we melt the surrounding plastic and cool it to install the insert.

# Local Variables:
# org-html-postamble: nil
# End:

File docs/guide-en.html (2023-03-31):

# CQ-80 Terminal Replica DIY Guide

## Table of Contents

- 1. Overview
- 2. Download files
- 3. 3d-printed parts
- 4. Fitting the parts
- 5. Install threaded inserts to the printed parts
- 6. Uploading the program to the microcontroller
- 7. Printing PCB boards
- 8. Soldering electronic parts
- 9. Painting the parts
  - 9.1. Materials
  - 9.2. Steps for painting
- 10. Assembly
- 11. Caring
- 12. If you don’t want the electronics
- 13. Parts listing

## 1. Overview

The CQ-80 replica is made of 3d-printed parts and (mostly) off-the-shelf electronic parts. The electronics allow it to connect to a computer via Bluetooth and control music playback. (It’s possible to exclude electronics, see below.)

To make the replica, you need to 3d-print the parts, paint them, buy all the electronics, solder them, upload a program to the microcontroller, and finally assemble everything together. I’d say that fitting the parts and painting them are the most difficult and time-consuming steps in the whole process.

Disclaimer: I’m an utter armature on 3d modeling, electronics and model painting. So dispite my best effort, there are short-comings all over the place. If you have any suggestion/feedback, I appreciate them very much.

NOTE!! The v3.0 (the latest) 3D models doesn’t match some of the photos below (taken from a v2.1 model), because I’ve made updates to the model but haven’t printed them yet (because reasons). But those changes are mostly minor, so it shouldn’t be a problem.

## 2. Download files

Download model and PCB files from here: TODO (it just links to the GitHub release). Unpack it and you should see two directory, stl ad controller, and two zip files, board.zip, usb_breakout.zip. The stl directory contains 3d model files; the controller directory is the Arduino program, and board.zip and usb_breakout.zip are files for printing the PCB board. Their use are explained as we go through each step.

## 3. 3d-printed parts

There are eight parts: the top and bottom shells, thumbstick and thumbstick guard, front bar, left and right side bars, the trademark insert on the top, and the hanger at the tail. The 3d model files for them are in the stl folder. I combined smaller parts together into a single file, so you only need to print three main parts: the top shell, the bottom shell, and the small parts combined.

I made the trade mark insert a separate piece, so you can design a custom insert and use that instead.



Figure 1: 3d-printed parts and their canonical name

I recommend printing using resin. MJF or SLS are ok, but they have fuzzy detail and uneven surface, and we don’t need the strength they provide. A strong resin is more than enough for our parts. Don’t use FDM. Its resolution is too low, and some structures in the parts simply cannot be printed with FDM.

I used pcbway.com for printing, they so much cheaper than sites like Shapeways and Xometry, and the result is not bad. If you are not concerned with budget, you can try Xometry, their quality is top-notch (but I haven’t tried their resin prints, only SLS prints). On pcbway.com I printed the top and bottom shell with Resin Somos EvoLVe 128, and the small parts with Resin UTR 8220. All three parts combined costs around $50 including shipping, really can’t complain.

[Here is a description of 3d-printing technologies I mentioned above: 3D Printing Technology Comparison: FDM vs. SLA vs. SLS (https://formlabs.com/blog/fdm-vs-sla-vs-sls-how-to-choose-the-right-3d-printing-technology/). SLS and MJF are quite similar, what it says about SLS pretty much applies to MJF too.]

## 4. Fitting the parts

Once you receive the parts, you need to sand/file them a bit here and their so everything fits together. The fitting in the digital model is pretty tight, since you can always sand down tight fits but it’s really hard to fix a loose fit.

You can get some small files (round, square and flat) from local hobby stores, they are very handy for fitting parts.

## 5. Install threaded inserts to the printed parts

Out of the eight parts, top and bottom shell are fastened together by two screws, thumbstick guard and hanger are glued to the top shell, and trademark insert and side bars are friction-fit. The PCB board and USB breakout board are screwed into the bottom shell.

Therefore, we need to install threaded inserts to top and bottom shells. The parts are designed to use M2 screws and M2 threaded inserts. Here is a tutorial on installing heat-set inserts: Using Heat Set Inserts (https://markforged.com/resources/blog/heat-set-inserts). You need iron and heat-set insert tip (or just the iron tip, it works ok). Do not press too hard when installing threaded inserts: the resin is strong but brittle, and is heat-resistant, so pressing too hard will break it. Be patient and press it in little by little.

Install inserts on these places:



Figure 2: Top shell



Figure 3: Bottom shell

## 6. Uploading the program to the microcontroller

You need a computer, a micro-usb cable and the Adafruit microcontroller.

1. Follow this guide—Arduino Support Setup (https://learn.adafruit.com/bluefruit-nrf52-feather-learning-guide/arduino-bsp-setup)—to install Arduino IDE and support software. The board we use is nRF52832, follow instructions for nRF52832 and ignore ones for nRF52840.
2. Test that everything is working fine by following this guide—Arduino Board Testing (https://learn.adafruit.com/bluefruit-nrf52-feather-learning-guide/arduino-board-setup). Don’t skip this step.
3. Use the Arduino IDE to open /arduino/controller/controller.ino, and hit the right-pointing arrow to upload the program. The board and port settings should be already set by the previous step when we test the board.

## 7. Printing PCB boards

There are two boards to print, the main board (board.zip) and the USB breakout board (usb_breakout.zip). I used OSHPARK (https://oshpark.com/) to print PCB boards. There are cheaper providers that I haven’t tried like pcbway (https://www.pcbway.com/) and jlcpcb (https://jlcpcb.com/).

Take OSHPARK as an example, go onto their website and click “browse for files”, and choose the zip file for the board, upload it, then hit continue all the way. Use USPS for shipping ;-)

## 8. Soldering electronic parts

Test before soldering any parts! Test that the LED’s and resistors work! You’ll be in a world of pain if you find out a resister is bad after you’ve soldered it to the board.

1. Solder the microcontroller to the main board
2. Solder the joystick to the main board (you need to clip the two nubs under the joystick part because I forgot to create holes on the pcb board design)
3. Solder the USB female connector to the USB breakout board
4. Connect the USB breakout board to the micro-USB connector (the square hole on the breakout is ground)
5. Solder resistors to the main board (for the LED’s anything around 100ω is fine, for the battery detection, use something large like 10kω)
6. Solder header pins for the LED’s to the main board
7. Solder some jumper wires to the LED’s and connect them to the header pins on the main board.

Of course, you can use LED’s of whatever color you like, just make sure the dimensions (5mm, 3mm, 8mm) are right.



Figure 4: Main board



Figure 5: USB board.

## 9. Painting the parts

### 9.1. Materials

I don’t have aerospray so I hand-painted the parts. I tried to use paints that are allegedly friendly to hand-painting. You can find a list of the paints I used below in the painting section.

If you don’t want to hand-paint and don’t have aerospray, you can get some spray cans and spray paint. I didn’t spray paint because I couldn’t find the exact color I want. When buying spray paint, make sure to by spray paints for modeling, like Tamiya and Mr. Hobby, not ones for graffiti or painting furnitures.

I used Pallid Wych Flesh (off-white) for the primary color of the top shell, and Pallid Wych Flesh mixing in a little bit Rakarth Flesh (brownish) for the bottom shell and the alt color on the top shell. For the violet red color (thumbstick, etc), I mixed Violet Red plus a little bit of Carmine Red. Carmine Red is probably optional, if you don’t mind your thumbstick to be a bit more purple than the official one.

This is the rough ratio for the paints, to the best of my recollection:

Top shell

Pallid Wych Flesh

Bottom shell & top shell alt

Pallid Wych Flesh : Rakarth Flesh = 7 : 1, maybe

Thumbstick, etc

Violet Red : Carmine Red = 5 : 1, possibly

Grey parts

Just the color of light grey primer (see below)

I really don’t remember… Luckily the two colors that requires mixing have large rooms of error.

### 9.2. Steps for painting

I learned this from watching accumulatively ~4.78 hrs of gunpla and 3d printing videos on YouTube, so don’t take my word for everything.

But anyway, you need to first fill the gaps like print-lines or other imperfections with acrylic putty, then sand the surfaces smooth. It should be very smooth to the touch, because any small imperfections you can’t see right now will show when you put on paint. You can get some sanding sponge which are very handy when sanding small models like this (you can find them at a local hobby store). I suggest you leave the putty to dry for at least a couple hours, ideally overnight, before sanding. Just casually put on some putty, let it dry, sand it next day, add more putty if necessary, and repeat. Take it slow and easy. Don’t rush it or get it done in one afternoon. This advice applies to the following steps as well.

Once the surface is smooth, prime your parts with a light grey primer. For grey parts this is all they need. For other parts, the next step is to apply paint.

I suggest you first watch some hand-painting gunpla/miniature tutorials on YouTube before doing it, because it’s not too easy. Buy some nice, soft acrylic painting brush, don’t use cheap ones. The key seems to be thinning the paint just right: not too thin and not too thick. Also be patient and work layer by layer. The first and second layers are going to look really bad and it’s fine, after several layers you should get a pretty uniform color. If you are patient and apply thin layers, there is a larger room of error.

Finally, let the paint dry for a couple of hours and spray all the parts with a layer or two of clear top-coat to protect the paint. I used gloss top-coat because the in-game render seems to be glossy. And the end result is indeed very nice. If you want, you can use flat or half-gloss top-coat. After applying the top-coat, I suggest you to leave it along for at least a couple hours, ideally a day before touching it.

## 10. Assembly

Bottom shell:

1. Install the LED’s. I suggest using hot glue gun to glue them in-place. Also make sure you test the LED’s before gluing them.
2. Screw the USB breakout to the bottom shell
3. Plug in the battery to the microcontroller
4. Plug in the micro USB plug to the micro controller
5. Screw the main board to the bottom shell, tuck the battery under the main board

Top shell:

1. Glue the thumstick guard into place, I used super glue
2. Glue the LED’s into place, I used hot glue gun
3. Glue the hanger into place (super glue)
4. Glue the front bars (super glue)

Assemble:

1. Plug in LED’s wires to the main board
2. Install the thumbstick
3. Screw the top and bottom shell together
4. Install side bars.



Figure 6: Installing the USB breakout board. Technically you only need to connect the +5 and GND pins, like I did here. These two pins allows you to charge the battery through the USB port. But if you connect all four pins, you can use the USB port for uploading programs as well.



Figure 7: Installing the main board.

## 11. Caring

Even though we sprayed a protective top-coat, the paint is still easily damaged: I’ve had small dents on the CQ-80 that are deep enough to reveal underling primer. I guess spray painitng will give you a thinner and more robust paint, I’m also contemplating on using auto top-coats, I’ll report back with the result.

Anyway, the best way to protect the paint job is to not knock anything into it. Put it in a bag or a crystal coffin so nothing sharp can hit it.

## 12. If you don’t want the electronics

It should be quite feasible to do away all the electronics, should you only want the plastic model and don’t care about the music controller functionality. It’ll also cut the cost by a lot. You still need the joystick, just glue it to a cardboard or something, and glue the cardboard to the pole right under the joystick. I’d also reinforce the pole, eg, smudge a pile of hot glue around it.

## 13. Parts listing

3d-printed parts (in the stl folder):

- Top shell
- Bottom shell
- Thumbstick
- Thumbstick guard
- Front bar
- Side bars
- Trademark insert
- Hanger

Mechanical parts:

- M2¹ screws (https://www.amazon.com/s?k=M2+screws+12mm) (8mm in length) × 4
- M2 screws (4mm) × 4
- Heat-set² M2 threaded inserts (https://www.amazon.com/s?k=M2+heat-set+threaded+insert+3.5+x+4) (4mm × 3.5mm) (length × outer diameter) × 8

Printed PCB boards:

- Main board (board.zip)
- USB breakout (usb_breakout.zip)

Electronic parts:

- Adafruit Feather nRF52 Bluefruit LE (nRF52832) (https://www.adafruit.com/product/3406) (nRF52840 should also work if you know how to modify the program)
- Adafruit Lithium Ion Battery 3.7V 1200mAh (https://www.adafruit.com/product/258)
- Alps RKJXV1224 joystick (https://www.amazon.com/s?k=switch+pro+controller+replacement+joystick) (aka switch pro controller replacement joystick)
- Molex USB 2.0 type-A female vertical mount connector (https://www.digikey.com/en/products/detail/molex/1050570001/3045207) (product number ‎1050570001‎)
- USB Micro-B connector (https://www.amazon.com/gp/product/B07G5ZY7MH/ref=ppx_yo_dt_b_search_asin_title?ie=UTF8&psc=1) (anything similar-sized should work)
- Micro USB to USB cable (for uploading the program to the microcontroller)
- USB male to USB male cable (https://www.amazon.com/s?k=USB+male+to+USB+male&ref=nb_sb_noss) (for charging CQ-80)

Electronic consumables:

- 5mm red LED (https://www.amazon.com/s?k=5mm+led&crid=1DRG7DU8VXT7J&sprefix=5mm+led%2Caps%2C145&ref=nb_sb_noss_1) × 1 (top light)
- 3mm green LED (https://www.amazon.com/s?k=3mm+led&crid=4JJ4EKJP17Q3&sprefix=3mm+le%2Caps%2C131&ref=nb_sb_noss_2) × 1 (front lamp)
- 8mm white LED (https://www.amazon.com/s?k=8mm+led&crid=FJQQ6UVY7NAI&sprefix=8mm+led%2Caps%2C140&ref=nb_sb_noss_1) × 1 (head light)
- 5mm warm-white LED (https://www.amazon.com/s?k=5mm+led&crid=1DRG7DU8VXT7J&sprefix=5mm+led%2Caps%2C145&ref=nb_sb_noss_1) × 2 (side lights)
- Resistors (https://www.amazon.com/s?k=resistors), 110Ω × 4, 10KΩ × 1. The resistance doesn’t have to be exact, 110Ω ones can be replaced by any resistor in the range of 50 to 300 ohms, and the 10K one can be replaced by any in the 10K-100K range.
- Jumper wires (female) (https://www.amazon.com/s?k=jumper+wires) (alternatively you can buy normal wires and Dupont pins (https://www.amazon.com/s?k=dupont+pins) and make jump wires yourself)
- Header pins (https://www.amazon.com/s?k=header+pins&ref=nb_sb_noss)

Painting:

- Citadel Colour, Layer, Pallid Wych Flesh (https://www.games-workshop.com/en-US/Layer-Pallid-Wych-Flesh-2019)
- Citadel Colour, Base, Rakarth Flesh (https://www.games-workshop.com/en-US/Base-Rakarth-Flesh-2019)
- Vallejo Model Color 70.812 Violet Red (https://acrylicosvallejo.com/en/product/hobby/model-color-en/violet-red-70812/)
- (optional) Vallejo Model Color 70.908 Carmine Red (https://acrylicosvallejo.com/en/product/hobby/model-color-en/carmine-red-70908/)
- Vallejo 70.401 Plastic Putty (https://acrylicosvallejo.com/en/product/crafts/auxiliaries-decorative-arts/plastic-putty/)
- Tamiya Fine Surface Primer Light Grey Spray Can (https://www.tamiyausa.com/shop/finishing/fine-surface-primer-l/)
- Mr. Super Clear UV Cut Gloss Top Coat (https://www.mr-hobby.com/en/product2/category_11/272.html) (Tamiya or Mr. Hobby doesn’t matter, any top-coat should work)
- Sanding sponge I mentioned earlier, should be easily found in local hobby stores

Tools:

- Soldering kit (iron & tin (https://www.amazon.com/s?k=soldering+iron), third hand (https://www.amazon.com/s?k=third+hand+soldering)) (for soldering and installing threaded inserts)
- (optional) Heat-set insert tip (https://www.amazon.com/dp/B08B17VQLD?psc=1&ref=ppx_yo2ov_dt_b_product_details) (for installing threaded inserts)
- Acrylic brushes

## Footnotes:

¹

“M2” is the “size” of the screw, read Thread types: The practical engineer’s guide (https://www.hubs.com/knowledge-base/thread-types/) for some explanations.

²

“Heat-set” means we melt the surrounding plastic and cool it to install the insert.

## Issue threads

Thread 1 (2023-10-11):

i cant find the stl files for CQ-80

JVGWTX, 2023-10-11:
i searched everywhere and couldent find it does someone know where  i can find the files for the cq-80

casouri, 2023-10-12:
You can find them here: https://github.com/casouri/cq-80/releases

JVGWTX, 2023-10-12:
Thank you so much : )

casouri, 2023-10-12:
Keep me updated! I'm curious of what you can make! Free free to ask me questions, too.

JVGWTX, 2023-10-25:
@casouri 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![Uploading 278120659...] well I'm in the process of building the CQ-80 and I wanted to thank you for the files and for your help it already looks beautiful but I'm going to make not the model of agent 8 I am going to make the model of Agent 3
In Octo Expansion thank you.

casouri, 2023-10-27:
That'll be very interesting to see! So it's gonna be blue, huh?

JVGWTX, 2023-10-27:
Yes exactly it's going to be blue but I need to reprint the secondary parts because they came not very good out of my printer but right now I'm in the process of sanding it down.

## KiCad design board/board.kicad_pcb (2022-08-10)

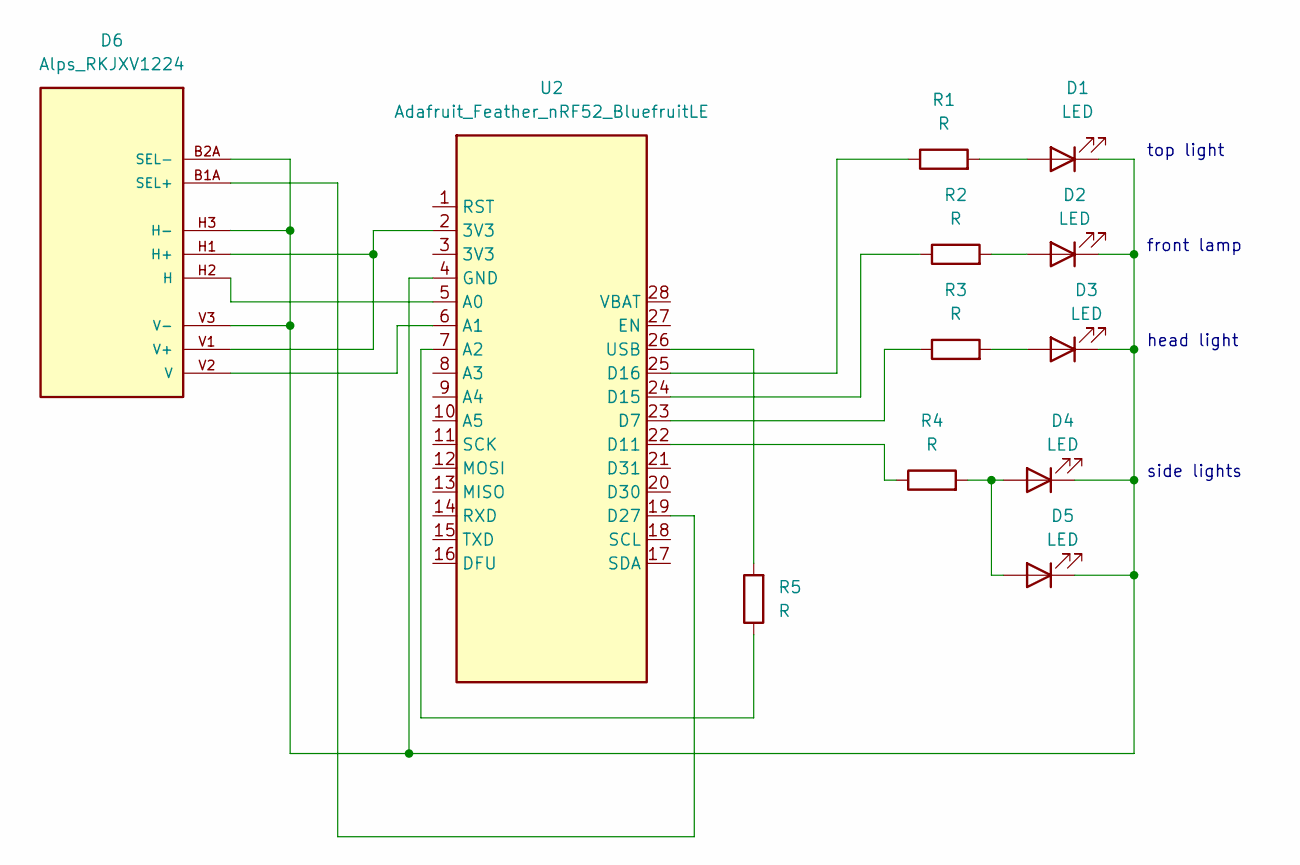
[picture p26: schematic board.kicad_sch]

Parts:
D1, D2, D3, D4, D5: LED; LED_D5.0mm_Clear
D6: Alps_RKJXV1224
R1, R2, R3, R4, R5: R; R_Axial_DIN0207_L6.3mm_D2.5mm_P10.16mm_Horizontal
U2: Adafruit_Feather_nRF52_BluefruitLE

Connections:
unnamed: D1.1 (K), D2.1 (K), D3.1 (K), D4.1 (K), D5.1 (K), D6.B2A (SEL-), D6.H3 (H-), D6.V3 (V-), U2.4 (GND)
unnamed: D1.2 (A), R1.2
unnamed: D2.2 (A), R2.2
unnamed: D3.2 (A), R3.2
unnamed: D4.2 (A), D5.2 (A), R4.2
unnamed: D6.B1A (SEL+), U2.19 (D27)
unnamed: D6.H1 (H+), D6.V1 (V+), U2.2 (3V3)
unnamed: D6.H2 (H), U2.5 (A0)
unnamed: D6.V2 (V), U2.6 (A1)
unnamed: R1.1, U2.25 (D16)
unnamed: R2.1, U2.24 (D15)
unnamed: R3.1, U2.23 (D7)
unnamed: R4.1, U2.22 (D11)
unnamed: R5.1, U2.7 (A2)
unnamed: R5.2, U2.26 (USB)

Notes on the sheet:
top light
front lamp
head light
side lights

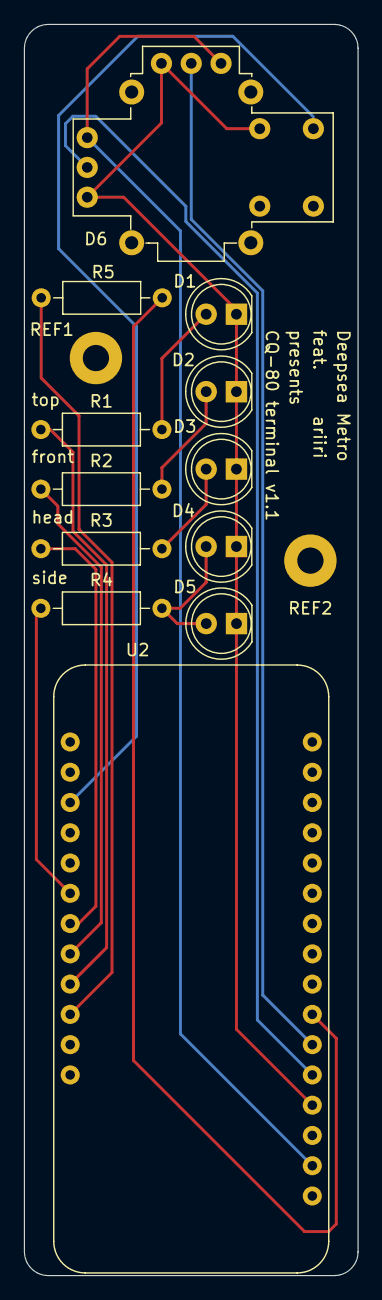
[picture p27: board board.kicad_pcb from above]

Board: 2 copper layers, 28.0 x 105.0 mm, 14 parts (0 on the bottom side), 15 nets.

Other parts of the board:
REF1, REF2: MountingHole_2.2mm_M2_Pad

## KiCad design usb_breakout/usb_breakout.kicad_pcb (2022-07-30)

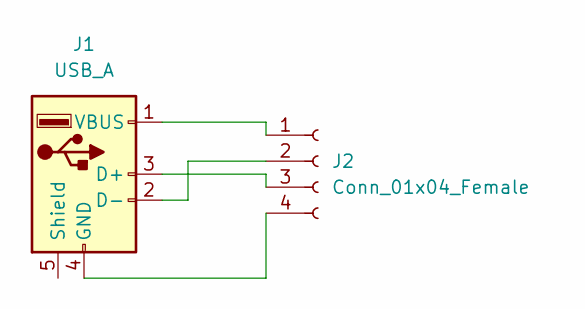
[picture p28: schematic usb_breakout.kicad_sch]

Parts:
J1: USB_A; USB_A_Molex_105057_Vertical
J2: Conn_01x04_Female; SolderWire-0.25sqmm_1x04_P4.2mm_D0.65mm_OD1.7mm

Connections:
unnamed: J1.1 (VBUS), J2.1
unnamed: J1.2 (D-), J2.2
unnamed: J1.3 (D+), J2.3
unnamed: J1.4 (GND), J2.4

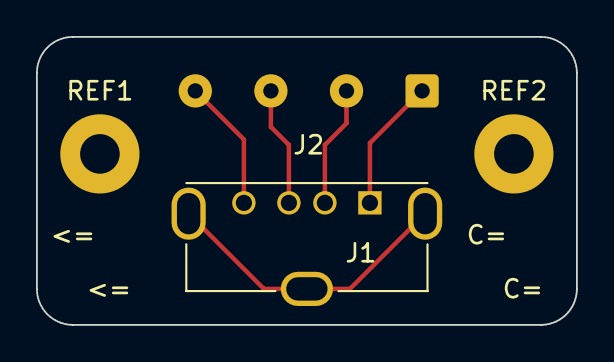
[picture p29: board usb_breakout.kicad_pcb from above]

Board: 2 copper layers, 30.0 x 16.0 mm, 4 parts (0 on the bottom side), 4 nets.

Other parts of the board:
REF1, REF2: MountingHole_2.2mm_M2_Pad

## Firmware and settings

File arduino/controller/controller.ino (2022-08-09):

/* This is the program for music controller functionality.

Actions:
 - Press joystick: toggle head and side light.
 - Press and hold joystick for 1s: If not paired, start pairing, top
   light blinks fast for 30 seconds (fast mode), then slow for 90s
   (slow mode).
 - Tilt up:
 - Tilt down: play/pause
 - Tilt left: previous track
 - Tilt right: next track
 - Rotate clockwise: volume up
 - Rotate counter-clockwise: volume down

The program also monitors battery voltage, and when it dips below
3.3V, front lamp starts blinking, when the voltage rises above 4.1V,
blinking stops.

The main loop runs every 100ms. This interval is long enough to save
battery life and short enough to be responsive.

When connection breaks, the program automatically starts re-pairing
without blinking the top light. */

#include <bluefruit.h>

/* Joystick Position. */
enum JoyPos {
  JoyPosUp,
  JoyPosDown,
  JoyPosLeft,
  JoyPosRight,
  JoyPosCenter,
};

/* Controller event. */
enum Event {
  EventTiltDown,
  EventTiltUp,
  EventTiltLeft,
  EventTiltRight,
  EventClockwise,
  EventCounterClockwise,
  EventClick,
  EventClickHold,
  EventNull,
};

enum ClickState {
  ClickState0,
  ClickStatePressed,
  ClickStateHoldDetected,
};

enum LightState {
  LightStateOff,
  LightStateSide,
  LightStateHead,
  LightStateBoth,
};

enum LayoutMode {
  LayoutModeMusic,
  LayoutModeStudy,
};

const int mediaPlayPause = 0xCD;
const int mediaNext = 0xB5;
const int mediaPrevious = 0xB6;
const int mediaVolumeUp = 0xE9;
const int mediaVolumeDown = 0xEA;
const int mediaRandom = 0xB9;
const int mediaSeekForward = 0xC0;
const int mediaSeekBackward = 0xC1;
LayoutMode currentMode = LayoutModeMusic;

const int led1Pin = 17;
const int led2Pin = 19;

/* Pin for joystick x-axis. */
const int xPin = 2;
/* Pin for joystick y-axis. */
const int yPin = 3;
/* Pin for clicking the joystick. */
const int clickPin = 27;
unsigned long clickPressStart = 0;
ClickState clickState = ClickState0;
/* The max reading from an axis. */
const int joyMaxRange = 946;
const int joyRange = joyMaxRange / 2;
/* Reading below this is considered being in center region. */
const int joyCenterRange = joyRange / 2;
/* Last position we read. */
JoyPos lastPos = JoyPosCenter;
/* Last three positions we read. */
JoyPos posHistory[3] = {JoyPosCenter, JoyPosCenter, JoyPosCenter};

/* Bitmaps for controlling each light, in the order of top light, front
   lamp, head light, side lights. */
/* The time when blinking stated. */
const int lightPin[4] = { 16, 15, 7, 11 };
LightState lightState = LightStateOff;

/* We connect USB to A2 to detect if usb port is plugged in. */
const int usbPin = 4;
/* This pin is used to measure battery voltage. */
const int batteryPin = 31;

/* BLE device information object. */
BLEDis bledis;
/* BLE keyboard object. */
BLEHidAdafruit blehid;
const int advertizeFastModeTimeout = 30;
const int advertizeTimeout = 120;

/* https://github.com/adafruit/Adafruit_nRF52_Arduino/blob/527e62d5f480c3f7f529bba06d88cd165de14626/cores/nRF5/utility/SoftwareTimer.h */
SoftwareTimer frontLampBlinkTimer;
bool frontLampBlinkTimerRunning = false;
SoftwareTimer checkBatteryTimer;
SoftwareTimer mainLoopTimer;
SoftwareTimer topLightBlinkTimer;

void setup()
{
  /* This seems to save some power. */
  NRF_POWER->DCDCEN = 1;
  /* Serial.begin(115200); */

  pinMode(led1Pin, OUTPUT);
  pinMode(led2Pin, OUTPUT);
  pinMode(lightPin[0], OUTPUT);
  pinMode(lightPin[1], OUTPUT);
  pinMode(lightPin[2], OUTPUT);
  pinMode(lightPin[3], OUTPUT);
  pinMode(clickPin, INPUT_PULLUP);
  pinMode(usbPin, INPUT);
  pinMode(batteryPin, INPUT);
  digitalWrite(lightPin[0], LOW);
  digitalWrite(lightPin[1], LOW);
  digitalWrite(lightPin[2], LOW);
  digitalWrite(lightPin[3], LOW);

  Bluefruit.begin();
  /* Turn off the blue led that lights up when auto connection is
     on. */
  Bluefruit.autoConnLed(false);
  Bluefruit.setTxPower(4); // 4dBm, 2.5mW, 10m range.
  Bluefruit.setName("CQ-80");
  Bluefruit.setAppearance(BLE_APPEARANCE_GENERIC_REMOTE_CONTROL);
  /* Set connection interval (min, max) to 30ms–60ms. (Unit is
     1.25ms). Apple has specific requirements, see advertize().
  */
  Bluefruit.Periph.setConnInterval(24, 48);

  bledis.setManufacturer("Deepsea Metro Inc.");
  bledis.setModel("CQ-80");
  bledis.begin();

  blehid.begin();
  advertize();

  frontLampBlinkTimer.begin(2000, frontLampBlinkRoutine);
  topLightBlinkTimer.begin(600, topLightBlinkRoutine);
  checkBatteryTimer.begin(1000, checkBatteryRoutine);
  checkBatteryTimer.start();
  mainLoopTimer.begin(100, mainLoop);
  mainLoopTimer.start();
  suspendLoop();
}

void loop() {}

void mainLoop(TimerHandle_t _handle)
{
  /* Process click. */
  switch (detectClickEvent())
    {
    case EventClick:
      if (Bluefruit.connected())
        {
          flashTopLight(random(1,7));
        }
      break;
    case EventClickHold:
      if (!Bluefruit.connected())
        {
          Bluefruit.Advertising.start(advertizeTimeout);
          advertizeStartCallback();
        }
      break;
    }

  /* Process joystick. Always light up top light regardless bluetooth
     connection. */
  int x = analogRead(xPin) - joyRange;
  int y = analogRead(yPin) - joyRange;
  JoyPos pos = readJoyPos(x, y, joyCenterRange);
  if (pos != JoyPosCenter)
    digitalWrite(lightPin[0], HIGH);
  else
    digitalWrite(lightPin[0], LOW);
  if (Bluefruit.connected())
    {
      if (pos != lastPos)
        {
          pushNewPos(pos, posHistory);
          Event event = detectEvent(posHistory);
          if (event == EventTiltUp)
            {
              toggleLight();
            }
          else {
            int mediaCode = eventToMediaCode(event, currentMode);
            if (mediaCode != 0)
              {
                /* Send media key. */
                blehid.consumerKeyPress(mediaCode);
                delay(5);
                blehid.consumerKeyRelease();
              }
          }
          lastPos = pos;
        }
    }
  delay(100);
}

/* Return the appropriate consumer key given the event. Returns 0 for
   EventNull. */
int eventToMediaCode(Event event, LayoutMode mode)
{
  switch (mode)
    {
    case LayoutModeMusic:
      switch (event)
        {
        case EventTiltDown:
          return mediaPlayPause;
        case EventTiltLeft:
          return mediaPrevious;
        case EventTiltRight:
          return mediaNext;
        case EventClockwise:
          return mediaVolumeUp;
        case EventCounterClockwise:
          return mediaVolumeDown;
        case EventNull:
          return 0;
        default:
          return 0;
        }
    case LayoutModeStudy:
      switch (event)
        {
        case EventTiltDown:
          return mediaPlayPause;
        case EventTiltLeft:
          return mediaSeekBackward;
        case EventTiltRight:
          return mediaSeekForward;
        case EventClockwise:
          return mediaVolumeUp;
        case EventCounterClockwise:
          return mediaVolumeDown;
        case EventNull:
          return 0;
        default:
          return 0;
        }
    default:
      return 0;
    }
}

/*** Joystick */

/* Read a pos from x and y coordinates.
 centerRange is the range defined to be the center. */
JoyPos readJoyPos(int x, int y, int centerRange)
{
  if (abs(x) < centerRange && abs(y) < centerRange)
    return JoyPosCenter;

  if (abs(x) > abs(y))
    {
      if (x < 0)
        return JoyPosLeft;
      else
        return JoyPosRight;
    }
  else
    {
      if (y < 0)
        return JoyPosDown;
      else
        return JoyPosUp;
    }
}

/* Push a new pos into position history. */
void pushNewPos(JoyPos pos, JoyPos posHistory[3])
{
  posHistory[0] = posHistory[1];
  posHistory[1] = posHistory[2];
  posHistory[2] = pos;
}

/* Figure out the proper event from past joystick positions. */
Event detectEvent(JoyPos posHistory[3])
{
  /* We use three history positions so we can distinguish between tile
     and rotation. */
  JoyPos p0 = posHistory[0];
  JoyPos p1 = posHistory[1];
  JoyPos p2 = posHistory[2];

  /* Tilt left. */
  if (p0 == JoyPosCenter && p1 == JoyPosLeft && p2 == JoyPosCenter)
    return EventTiltLeft;
  /* Tilt right. */
  if (p0 == JoyPosCenter && p1 == JoyPosRight && p2 == JoyPosCenter)
    return EventTiltRight;
  /* Tilt up. */
  if (p0 == JoyPosCenter && p1 == JoyPosUp && p2 == JoyPosCenter)
    return EventTiltUp;
  /* Tilt down. */
  if (p0 == JoyPosCenter && p1 == JoyPosDown && p2 == JoyPosCenter)
    return EventTiltDown;
  /* Clockwise rotation. */
  if (p1 == JoyPosLeft && p2 == JoyPosUp
      || p1 == JoyPosUp && p2 == JoyPosRight
      || p1 == JoyPosRight && p2 == JoyPosDown
      || p1 == JoyPosDown && p2 == JoyPosLeft)
    return EventClockwise;
  /* Counter-clockwise rotation. */
  if (p2 == JoyPosLeft && p1 == JoyPosUp
      || p2 == JoyPosUp && p1 == JoyPosRight
      || p2 == JoyPosRight && p1 == JoyPosDown
      || p2 == JoyPosDown && p1 == JoyPosLeft)
    return EventCounterClockwise;
  return EventNull;
}

/* Returns EventClick, EventClickHold, or EventNull. Mutates
   clickState, ClickPressStart, reads clickPin. */
Event detectClickEvent(void)
{
  switch (clickState)
    {
    case ClickState0:
      if (digitalRead(clickPin) == LOW)
        {
          clickState = ClickStatePressed;
          clickPressStart = millis();
        }
      return EventNull;
    case ClickStatePressed:
      if (digitalRead(clickPin) == HIGH)
        {
          clickState = ClickState0;
          return EventClick;
        }
      if (millis() - clickPressStart > 1000)
        {
          clickState = ClickStateHoldDetected;
          return EventClickHold;
        }
      /* At this point, we are still holding but didn’t reach 1s,
         return null event. */
      return EventNull;
    case ClickStateHoldDetected:
      /* Once we detect and sent a hold event, we don’t send further
         events whether the joystick is released or not. */
      if (digitalRead(clickPin) == HIGH)
        {
          clickState = ClickState0;
        }
      return EventNull;
    default:
      return EventNull;
    }
}

/*** BLE */

void advertize(void)
{
  /* Define advertising packet. */
  Bluefruit.Advertising.addFlags(BLE_GAP_ADV_FLAGS_LE_ONLY_GENERAL_DISC_MODE);
  Bluefruit.Advertising.addTxPower();
  /* Include BLE HID service. */
  Bluefruit.Advertising.addService(blehid);
  Bluefruit.ScanResponse.addName();
  /* Start Advertising
   * - Enable auto advertising if disconnected
   * - Interval:  fast mode = 20 ms, slow mode = 1285 ms.
   * - Timeout for fast mode is 30 seconds
   Apple has very specific interval requirements:
   https://developer.apple.com/library/archive/qa/qa1931/_index.html
   */
  Bluefruit.Advertising.restartOnDisconnect(true);
  /* Unit is 0.625ms. */
  Bluefruit.Advertising.setInterval(32, 2056);
  /* Set number of seconds in fast mode. */
  Bluefruit.Advertising.setFastTimeout(advertizeFastModeTimeout);
  /* Clean up after advertising stops. */
  Bluefruit.Advertising.setStopCallback(advertizeStopCallback);
  Bluefruit.Advertising.setStopCallback(advertizeSlowCallback);
  /* Bluefruit.setDisconnectCallback(advertizeStartCallback); */
  /* Start advertising and stop after n seconds, 0 = never stop. */
  Bluefruit.Advertising.start(advertizeTimeout);
}

void advertizeStartCallback(void)
{
  topLightBlinkTimer.setPeriod(250);
  topLightBlinkTimer.start();
}

void advertizeStopCallback(void)
{
  /* Turn off blinking. */
  topLightBlinkTimer.stop();
  digitalWrite(lightPin[0], LOW);
}

void advertizeSlowCallback(void)
{
  /* Slow down blinking. */
  topLightBlinkTimer.setPeriod(1000);
}

/* Blink top light, if fast mode is past, blink slower, if advertize
   timeout is past, stop blinking. */
void topLightBlinkRoutine(TimerHandle_t _handle)
{
  digitalToggle(lightPin[0]);
}

float readBatteryVoltage(void)
{
  /* REF: https://learn.adafruit.com/bluefruit-nrf52-feather-learning-guide/nrf52-adc */
  /* Default ADC range is 3.6V, resolution 10 bits. */
  const float vbatScale = 3600.0 / 1024.0;
  /* 2M + 0.806M voltage divider on VBAT = (2M / (0.806M + 2M)) =
     0.71275837F, the inverse of that is 1.403F. */
  const float vbatCompensation = 1.403;
  /* Hopefully compiler can compile these away? */
  return analogRead(batteryPin) * (vbatScale * vbatCompensation);
}

void frontLampBlinkRoutine(TimerHandle_t _handle)
{
  /* Timer examples: https://github.com/adafruit/Adafruit_nRF52_Arduino/pull/262/commits/63b43fc2ec1650398fdc0e104479d85706af844a */
  digitalToggle(lightPin[1]);
}

/* Blink front lamp when voltage drops below 3.3V (below 10%) and
   stops blinking when voltages raises above 4.1V (almost full). */
void checkBatteryRoutine(TimerHandle_t _handle)
{
  float batteryVoltage = readBatteryVoltage();
  float usbVoltage = analogRead(usbPin);
  /* Magic number, connected: 960+, disconnected: ~350. */
  bool charging = usbVoltage > 900 ? true : false;
  bool blink = false;
  bool output = LOW;
  if (!charging && batteryVoltage < 3300)
    {
      blink = true;
    }
  else if (charging && batteryVoltage < 4100)
    {
      blink = false;
      output = HIGH;
    }
  else
    {
      blink = false;
      output = LOW;
    }
  if (blink != frontLampBlinkTimerRunning)
    {
      if (frontLampBlinkTimerRunning)
        frontLampBlinkTimer.stop();
      else
        frontLampBlinkTimer.start();
      frontLampBlinkTimerRunning = !frontLampBlinkTimerRunning;
    }
  if (!blink)
    digitalWrite(lightPin[1], output);
}

/* Toggle between each light layout. */
void toggleLight(void)
{
  switch (lightState)
    {
    case LightStateOff:
      lightState = LightStateSide;
      digitalWrite(lightPin[2], LOW);
      digitalWrite(lightPin[3], HIGH);
      break;
    case LightStateSide:
      lightState = LightStateHead;
      digitalWrite(lightPin[2], HIGH);
      digitalWrite(lightPin[3], LOW);
      break;
    case LightStateHead:
      lightState = LightStateBoth;
      digitalWrite(lightPin[2], HIGH);
      digitalWrite(lightPin[3], HIGH);
      break;
    case LightStateBoth:
      lightState = LightStateOff;
      digitalWrite(lightPin[2], LOW);
      digitalWrite(lightPin[3], LOW);
      break;
    }
}

void flashTopLight(int n)
{
  for (int count=0; count < n; count++)
    {
      digitalWrite(lightPin[0], HIGH);
      delay(100);
      digitalWrite(lightPin[0], LOW);
      delay(100);
    }
}

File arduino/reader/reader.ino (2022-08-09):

/* Joystick Position. */
enum JoyPos {
  JoyPosUp,
  JoyPosDown,
  JoyPosLeft,
  JoyPosRight,
  JoyPosCenter,
};

enum Event {
  EventPlayPause,
  EventBack,
  EventForward,
  EventVolumeUp,
  EventVolumeDown,
  EventRandom,
  EventNull,
};

const int xPin = 2;
const int yPin = 3;
const int joyMaxRange = 946;
const int joyRange = joyMaxRange / 2;
const int joyCenterRange = joyRange / 2;
JoyPos lastPos = JoyPosCenter;
JoyPos posHistory[3] = {JoyPosCenter, JoyPosCenter, JoyPosCenter};

/* Default ADC range is 3.6V, resolution 10 bits. */
const float vbatScale = 3600.0 / 1024.0;
/* 2M + 0.806M voltage divider on VBAT = (2M / (0.806M + 2M)) =
   0.71275837F, the inverse of that is 1.403F. */
const float vbatCompensation = 1.403;

void setup()
{
  Serial.begin(115200);
  pinMode(31, INPUT);
  pinMode(4, INPUT);
}

void loop()
{
  float vbat = analogRead(31) * (vbatScale * vbatCompensation);
  float usb = analogRead(4);
  Serial.print("VBat: " ); Serial.println(vbat);
  Serial.print("USB: " ); Serial.println(usb);
  delay(1000);
}

/* void loop() */
/* { */
/*   int x = analogRead(xPin); */
/*   int y = analogRead(yPin); */
/*   Serial.print("x="); */
/*   Serial.print(x); */
/*   Serial.print(" y="); */
/*   Serial.println(y); */
/*   delay(50); */
/* } */

/* void loop () */
/* { */
/*   int x = analogRead(xPin) - joyRange; */
/*   int y = analogRead(yPin) - joyRange; */

/*   JoyPos pos = readJoyPos(x, y, joyCenterRange); */
/*   switch (pos) */
/*     { */
/*     case JoyPosUp: */
/*       Serial.println("Up"); */
/*       break; */
/*     case JoyPosDown: */
/*       Serial.println("Down"); */
/*       break; */
/*     case JoyPosLeft: */
/*       Serial.println("Left"); */
/*       break; */
/*     case JoyPosRight: */
/*       Serial.println("Right"); */
/*       break; */
/*     case JoyPosCenter: */
/*       Serial.println("Center"); */
/*       break; */
/*     } */

/*   delay(50); */
/* } */

/* void loop () */
/* { */
/*   int x = analogRead(xPin) - joyRange; */
/*   int y = analogRead(yPin) - joyRange; */

/*   JoyPos pos = readJoyPos(x, y, joyCenterRange); */
/*   if (pos != lastPos) */
/*     { */
/*       pushNewPos(pos, posHistory); */
/*       Event event = detectEvent(posHistory); */
/*       switch (event) */
/*         { */
/*         case EventPlayPause: */
/*           Serial.println("PlayPause"); */
/*           break; */
/*         case EventBack: */
/*           Serial.println("Back"); */
/*           break; */
/*         case EventForward: */
/*           Serial.println("Forward"); */
/*           break; */
/*         case EventVolumeUp: */
/*           Serial.println("Up"); */
/*           break; */
/*         case EventVolumeDown: */
/*           Serial.println("Down"); */
/*           break; */
/*         case EventRandom: */
/*           Serial.println("Random"); */
/*           break; */
/*         case EventNull: */
/*           break; */
/*         } */
/*       lastPos = pos; */
/*     } */
/*   delay(50); */
/* } */

JoyPos readJoyPos(int x, int y, int centerRange)
{
  if (abs(x) < centerRange && abs(y) < centerRange)
    return JoyPosCenter;

  if (abs(x) > abs(y))
    {
      if (x < 0)
        return JoyPosLeft;
      else
        return JoyPosRight;
    }
  else
    {
      if (y < 0)
        return JoyPosDown;
      else
        return JoyPosUp;
    }
}

void pushNewPos(JoyPos pos, JoyPos posHistory[3])
{
  posHistory[0] = posHistory[1];
  posHistory[1] = posHistory[2];
  posHistory[2] = pos;
}

Event detectEvent(JoyPos posHistory[3])
{
  JoyPos p0 = posHistory[0];
  JoyPos p1 = posHistory[1];
  JoyPos p2 = posHistory[2];

  if (p0 == JoyPosCenter && p1 == JoyPosLeft && p2 == JoyPosCenter)
    return EventBack;
  if (p0 == JoyPosCenter && p1 == JoyPosRight && p2 == JoyPosCenter)
    return EventForward;
  if (p0 == JoyPosCenter && p1 == JoyPosUp && p2 == JoyPosCenter)
    return EventRandom;
  if (p0 == JoyPosCenter && p1 == JoyPosDown && p2 == JoyPosCenter)
    return EventPlayPause;
  if (p1 == JoyPosLeft && p2 == JoyPosUp
      || p1 == JoyPosUp && p2 == JoyPosRight
      || p1 == JoyPosRight && p2 == JoyPosDown
      || p1 == JoyPosDown && p2 == JoyPosLeft)
    return EventVolumeUp;
  if (p2 == JoyPosLeft && p1 == JoyPosUp
      || p2 == JoyPosUp && p1 == JoyPosRight
      || p2 == JoyPosRight && p1 == JoyPosDown
      || p2 == JoyPosDown && p1 == JoyPosLeft)
    return EventVolumeDown;
  return EventNull;
}

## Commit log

2022-07-27 Add supports to top shell
    [cq-80.FCStd]
2022-07-27 Cut all the grooves
2022-07-27 Fused all the bumps
2022-07-27 Slim-down top shell
    [cq-80.FCStd]
2022-07-27 Fuse all supports
2022-07-27 Cut cutouts
2022-07-27 Cut grooves
2022-07-27 Fillet and cut trademark groove
2022-07-27 Fuse bump, cut cylinder
2022-07-27 Fuse groove supports
2022-07-27 Screw support
2022-07-27 Fix screw support
2022-07-27 Hole in top shell
2022-07-28 Add lamp slots
2022-07-28 Adjust fitting of screw support
2022-07-28 Bottom screw support
2022-07-28 Bottom screw mirror
2022-07-29 Bottom alignment rails
2022-07-29 Adjust screw support
2022-07-29 Side rails
2022-07-29 Front rails
2022-07-30 pcb support and usb port
2022-07-30 Add pcb design for board and usb breakout
    [board-B_Cu.gbr, board-B_Mask.gbr, board-B_Paste.gbr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]
2022-07-31 Cut bottom parts
2022-07-31 Move up cut master
2022-07-31 Adjust bottom screw support hole
2022-07-31 Cut out tail fin
2022-07-31 Half way merging top
    Need to fix chin plate
2022-07-31 Adjust chin plate and fuse tail
2022-07-31 Fused and fixed
2022-07-31 Rework tail & screw support
2022-07-31 Fix trademark insert
2022-08-01 Adjustments after prototype
2022-08-03 Add arduino code
2022-08-04 Add timer sketch
2022-08-04 Fix voltage reading code
    [reader.ino]
2022-08-04 * arduino/controller/controller.ino: Add battery indicator light
2022-08-04 * arduino/controller/controller.ino: Convert loop to timer.
2022-08-04 Use timer for top light blinking
    * arduino/controller/controller.ino: Change main loop blinking to
    timer-based blinking.
2022-08-04 Start battery check with fast inteval
    * arduino/controller/controller.ino: When system starts, use 1s
    interval for battery check, we can later change it to 1h when we go
    into sleep.
2022-08-06 Add comment, change pause to 100ms
    * arduino/controller/controller.ino: As title.
2022-08-06 * arduino/controller/controller.ino: Add light toggle to up tilt.
2022-08-07 * arduino/controller/controller.ino: Rework events.
    [controller.ino]
2022-08-09 * arduino/controller/controller.ino: Enable dcdc.
2022-08-09 * arduino/controller/controller.ino: Add back both state.
2022-08-09 * arduino/controller/controller.ino: Detect charging.
2022-08-09 * arduino/controller/controller.ino (lightPin): Change back.
2022-08-09 * arduino/controller/controller.ino: Refactor advertize blinking.
2022-08-09 * arduino/controller/controller.ino (advertize): Add slowcallback.
2022-08-09 * arduino/reader/reader.ino: Add usb reading.
2022-08-09 Cut materials (card, fin)
2022-08-09 Cut materials (tail support)
2022-08-09 Shrink & fix screw support
2022-08-09 * arduino/controller/controller.ino: Always light when joystick move
2022-08-09 * arduino/controller/controller.ino: More callback.
2022-08-09 * arduino/controller/controller.ino: Fix charging indicator logic.
    [controller.ino]
2022-08-09 ; * arduino/reader/reader.ino: Minor change.
2022-08-10 * board: Add usb pin and second side light led
    [board.kicad_pcb, board.kicad_sch]
2022-08-10 Fix usb port support’s insert hole
2022-08-10 * docs/index.org: Fix description of M2 screws.
